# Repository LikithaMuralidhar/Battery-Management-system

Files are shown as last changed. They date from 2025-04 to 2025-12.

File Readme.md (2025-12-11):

# Battery Management System for 48V Lithium-Ion Battery Pack

**A comprehensive BMS solution for 48V Li-Ion battery packs with real-time monitoring and protection**

</div>

---

## Table of Contents

- [Overview](#-overview)
- [Features](#-features)
- [Specifications](#-specifications)
- [Hardware Components](#-hardware-components)
- [PCB Design](#-pcb-design)
- [Software Interface](#-software-interface)
- [Installation](#-installation)
- [Usage](#-usage)
- [Results](#-results)
- [Safety](#-safety)
- [Contributing](#-contributing)
- [Acknowledgments](#-acknowledgments)

---

## Overview

This project presents a complete Battery Management System (BMS) designed for 48V Lithium-Ion battery packs. The system provides comprehensive monitoring, protection, and balancing capabilities for applications such as electric vehicles, e-bikes, and energy storage systems.

### Key Highlights

-  13S10P Configuration (130 cells total)
-  Real-time monitoring via JBD Tools software
- Active cell balancing
- Multiple protection mechanisms
- Open-source PCB design using KiCad
- Tested with 1.2kW BLDC Hub Motor

---

## Features

### Protection Systems

| Feature | Description |
|---|---|
| **Overvoltage Protection** | Individual cell and pack monitoring |
| **Undervoltage Protection** | Prevents deep discharge damage |
| **Overcurrent Protection** | Charging (6.5A) and discharging limits |
| **Temperature Monitoring** | Real-time thermal tracking |
| **Cell Balancing** | Automatic balancing (±40mV threshold) |
| **Short Circuit Protection** | Immediate fault detection |
| **MOSFET Control** | Separate charge/discharge management |

### Monitoring Capabilities

- Real-time voltage for all 13 series cells
- Pack voltage measurement
- Bidirectional current sensing
- Temperature monitoring
- State of Charge (SoC) estimation
- Cycle count tracking
- Comprehensive alert system

---

## Specifications

### Battery Pack

```yaml
Voltage: 48V (46.8V nominal)
Configuration: 13S10P (13 series, 10 parallel)
Total Cells: 130 cells
Cell Type: 18650 Lithium-Ion
Cell Voltage: 3.6V nominal
Cell Capacity: 2900mAh (2.9Ah)
Pack Capacity: 29Ah
Total Energy: ~1.4kWh
```

### Load System

```yaml
Motor Type: BLDC Hub Motor
Motor Rating: 48V, 530 RPM, 1.2kW
Charger: 54.2V, 6A
Max Charging Current: 6.35A
Operating Temperature: -20°C to 60°C
```

### Protection Thresholds

| Parameter | Min | Max | Unit |
|---|-----|-----|---|
| Cell Voltage | 2.5 | 4.2 | V |
| Pack Voltage | 32.5 | 54.6 | V |
| Charge Current | - | 6.5 | A |
| Discharge Current | - | 30 | A |
| Temperature | -10 | 60 | °C |

---

## Hardware Components

### Main Components

```
├── BMS Protection Board
│   ├── Microcontroller (STM32/ATmega)
│   ├── Voltage Sensing ICs
│   ├── Current Sensors
│   └── UART Communication
│
├── Power Stage
│   ├── Charge MOSFET
│   ├── Discharge MOSFET
│   └── Gate Drivers
│
├── Sensors
│   ├── NTC Thermistors
│   ├── Current Shunt Resistors
│   └── Voltage Divider Networks
│
└── Load System
    ├── BLDC Hub Motor
    ├── Motor Controller
    └── Throttle Interface
```

### Bill of Materials (BOM)

| Component | Quantity | Description |
|---|---|---|
| 18650 Li-Ion Cells | 130 | 2900mAh, 3.6V nominal |
| BMS IC | 1 | 13S protection board |
| N-Channel MOSFETs | 2 | Charge/Discharge control |
| Current Sensor | 1 | Hall effect or shunt-based |
| NTC Thermistor | 2-3 | Temperature monitoring |
| Nickel Strips | As needed | For spot welding |
| PCB | 1 | Custom designed |
| Connectors | Various | XT60, JST, etc. |

---

## PCB Design

### Design Tools

**Software:** [KiCad](https://www.kicad.org/) (Open-source EDA)

### Features
- Schematic capture with hierarchical design
- Multi-layer PCB layout
- DRC (Design Rule Check) compliant
- Gerber file generation
- 3D visualization
- SPICE simulation support

### Design Process

```mermaid
graph LR
    A[Schematic Design] --> B[Footprint Assignment]
    B --> C[PCB Layout]
    C --> D[Component Routing]
    D --> E[DRC Check]
    E --> F[Gerber Generation]
    F --> G[Manufacturing]
```

### PCB Specifications

- **Layers:** 2-4 layers
- **Dimensions:** Optimized for battery pack integration
- **Copper Weight:** 2oz for power traces
- **Finish:** HASL or ENIG
- **Files Included:**
  - Gerber files
  - Drill files
  - Pick and place files
  - BOM (Bill of Materials)

---

## Software Interface

### JBD Tools Software

#### Key Features

- **UART Communication** - Standard serial interface
- **Parameter Configuration** - Adjust protection thresholds
- **Real-time Monitoring** - Live data visualization
- **Alert System** - Protection status notifications
- **Data Logging** - Track battery performance

#### Monitored Parameters

```yaml
Cell Voltages: V1-V13 (individual)
Pack Voltage: Total voltage
Current: Charge/Discharge (A)
Temperature: Real-time (°C)
SoC: State of Charge (%)
Capacity: Remaining/Full (mAh)
Cycles: Total charge cycles
Balance Status: ON/OFF per cell
FET Status: Charge/Discharge MOSFET
Alerts: All protection triggers
```

---

## Installation

### Hardware Setup

#### 1. Battery Pack Assembly

```bash
# Materials Required
- 130x 18650 cells (matched capacity)
- Spot welding machine (5kVA recommended)
- Nickel strips (0.15mm thickness)
- Insulation sheets
- Heat shrink wrap
- BMS board
```

**Assembly Steps:**

1. **Cell Testing & Sorting**
   - Test all cells for capacity matching
   - Sort into groups with <50mAh difference
   - Charge all cells to 3.7V

2. **Spot Welding**
   - Create 10P groups using nickel strips
   - Connect 13 groups in series
   - Use proper welding current (50-80A, 0.1-0.2s)

3. **BMS Integration**
   - Connect balance wires (13 connections)
   - Connect main power terminals
   - Install temperature sensors
   - Mount BMS securely on pack

4. **Insulation & Packaging**
   - Apply insulation sheets
   - Wrap with heat shrink
   - Add terminal connectors

#### 2. Software Setup

```bash
# Download JBD Tools
# Available for Windows PC

1. Install JBD Tools software
2. Connect BMS via USB-UART adapter
3. Configure COM port settings
   - Baud rate: 9600
   - Data bits: 8
   - Stop bits: 1
   - Parity: None
```

### Configuration

```python
# Example protection parameters

Cell_OVP = 4.2V      # Overvoltage protection
Cell_UVP = 2.5V      # Undervoltage protection
Pack_OVP = 54.6V     # Pack overvoltage
Pack_UVP = 32.5V     # Pack undervoltage
Charge_OCP = 6.5A    # Charge overcurrent
Discharge_OCP = 30A  # Discharge overcurrent
Balance_Voltage = 40mV  # Balance threshold
Temp_High = 60°C     # High temperature limit
Temp_Low = -10°C     # Low temperature limit
```

---

## 📖 Usage

### Basic Operation

#### Charging

```bash
1. Connect approved charger (54.2V, 6A max)
2. Monitor charging via JBD Tools
3. Charging stops automatically when:
   - Pack voltage reaches 54.6V
   - Any cell reaches 4.2V
   - Current exceeds 6.5A
   - Temperature exceeds limits
```

#### Discharging

```bash
1. Connect load (e.g., BLDC motor)
2. Monitor discharge parameters
3. BMS will disconnect if:
   - Pack voltage < 32.5V
   - Any cell < 2.5V
   - Current exceeds limits
   - Temperature out of range
```

#### Cell Balancing

```bash
# Automatic process
- Activates when cell voltage difference > 40mV
- Balancing current: 50-100mA typical
- Status shown in JBD Tools as "ON"
- Typically occurs near full charge
```

### JBD Tools Interface

#### Main Display

```
┌─────────────────────────────────────────┐
│ Cell Voltages (V)  │  Balance │ Status  │
├─────────────────────────────────────────┤
│ Cell 1:  3.632     │          │  ✓      │
│ Cell 2:  3.631     │          │  ✓      │
│ ...                │          │         │
│ Cell 13: 3.637     │          │  ✓      │
├─────────────────────────────────────────┤
│ Pack Voltage:  47.39V                   │
│ Current:       0.00A                    │
│ Temperature:   24.3°C                   │
│ SoC:           45%                      │
│ Capacity:      12960/29000 mAh         │
│ Cycles:        22                       │
├─────────────────────────────────────────┤
│ Charge FET:    ON    Discharge FET: ON  │
└─────────────────────────────────────────┘
```

---

## 📊 Results

### Performance Validation

#### Test 1: Normal Operation
- **Pack Voltage:** 47.39V
- **Cell Voltage Range:** 3.632V - 3.667V (35mV spread)
- **Temperature:** 24°C
- **Status:** All protection systems operational 

#### Test 2: Charging Process
- **Charging Current:** 6.02A
- **Cell Voltage Range:** 3.693V - 3.737V
- **SoC:** 45% → Charging
- **Protection:** Overcurrent limit enforced at 6.5A 

#### Test 3: Cell Balancing
- **Balance Threshold:** 40mV
- **Active Balancing:** Cells 1, 5, 9 (marked "ON")
- **Pack Voltage:** 51.81V
- **SoC:** 74%
- **Result:** Successful voltage equalization 

#### Test 4: Discharging
- **Discharge Current:** -0.86A (motor at low speed)
- **Cell Voltage Range:** 3.617V - 3.658V
- **Pack Voltage:** 47.26V
- **SoC:** 45%
- **Motor Performance:** Stable operation 

### Key Achievements
 **Prototype Validation** - 4-cell design successfully scaled to 13S10P  
 **MATLAB Simulation** - Circuit analysis confirmed  
 **Protection Systems** - All safety mechanisms functional  
 **Temperature Monitoring** - Real-time tracking operational  
 **MOSFET Control** - Proper switching behavior verified  
 **Load Testing** - 1.2kW motor successfully powered  

---

## Safety

> Improper handling can result in fire, explosion, or injury.
> Always follow safety procedures.

### Safety Guidelines

#### DO:
- Use appropriate safety equipment (goggles, gloves)
- Work in well-ventilated areas
- Keep fire extinguisher nearby (Class D)
- Monitor temperature during operation
- Use manufacturer-approved chargers
- Inspect cells for damage before assembly
- Test BMS functionality before full assembly
- Store at 3.7-3.8V for long-term storage

#### DON'T:
- Exceed rated voltage or current limits
- Short circuit battery terminals
- Puncture or damage cells
- Expose to extreme temperatures
- Use damaged or swollen cells
- Charge unattended
- Bypass protection systems
- Mix cells of different capacities

### Emergency Procedures

```bash
# In case of thermal runaway:
1. Move to safe area away from flammable materials
2. Use Class D fire extinguisher
3. DO NOT use water
4. Evacuate area if fire spreads
5. Call emergency services
```

---

## Troubleshooting

### Common Issues

| Issue | Possible Cause | Solution |
|---|---|---|
| BMS not communicating | UART connection | Check COM port, baud rate |
| Cells not balancing | Voltage difference < 40mV | Normal, wait until higher SoC |
| Charge FET off | Overvoltage detected | Check cell voltages, reset BMS |
| Discharge FET off | Undervoltage detected | Charge battery pack |
| High temperature | Excessive current | Reduce load, improve cooling |
| SoC inaccurate | Calibration needed | Full charge/discharge cycle |

---

## Contributing

Contributions are welcome! Please follow these guidelines:

### How to Contribute

1. **Fork the repository**
2. **Create a feature branch** (`git checkout -b feature/AmazingFeature`)
3. **Commit changes** (`git commit -m 'Add AmazingFeature'`)
4. **Push to branch** (`git push origin feature/AmazingFeature`)
5. **Open a Pull Request**

### Development Setup

```bash
# Clone repository
git clone https://github.com/yourusername/48v-bms.git

# Navigate to project
cd 48v-bms

# Open KiCad project
kicad bms-48v.kicad_pro
```

### Code of Conduct

- Be respectful and inclusive
- Provide constructive feedback
- Focus on improving the project
- Follow coding standards

---

## 📁 Project Structure

```
48v-bms/
├── hardware/
│   ├── kicad/
│   │   ├── bms-schematic.kicad_sch
│   │   ├── bms-pcb.kicad_pcb
│   │   └── libraries/
│   ├── gerber/
│   │   └── manufacturing_files/
│   └── bom/
│       └── bill_of_materials.csv
│
├── software/
│   ├── jbd-tools/
│   │   └── configuration_files/
│   ├── matlab/
│   │   └── simulation_files/
│   └── firmware/
│       └── (firmware)
│
├── README.md
```

---

## 🎓 Acknowledgments

### Institution
**Department of Electrical and Electronics Engineering**  
**BNM Institute of Technology (BNMIT)**  
Academic Year: 2021-2022

### Special Thanks
- Faculty advisors for guidance and support
- Lab technicians for equipment access
- Fellow students for collaboration
- Open-source community (KiCad, GitHub)

### References
- Battery Management System Design Standards
- IEEE Standards for Battery Testing
- Lithium-Ion Battery Safety Guidelines
- KiCad PCB Design Best Practices

---

## Contact

### Project Maintainers

- **Email:** likithm18ee022@bnmit.edu.in
- **Institution:** BNMIT, Department of EEE

<div align="center">

**Made by BNMIT EEE Department**

[⬆ Back to Top](#-battery-management-system-for-48v-lithium-ion-battery-pack)

</div>

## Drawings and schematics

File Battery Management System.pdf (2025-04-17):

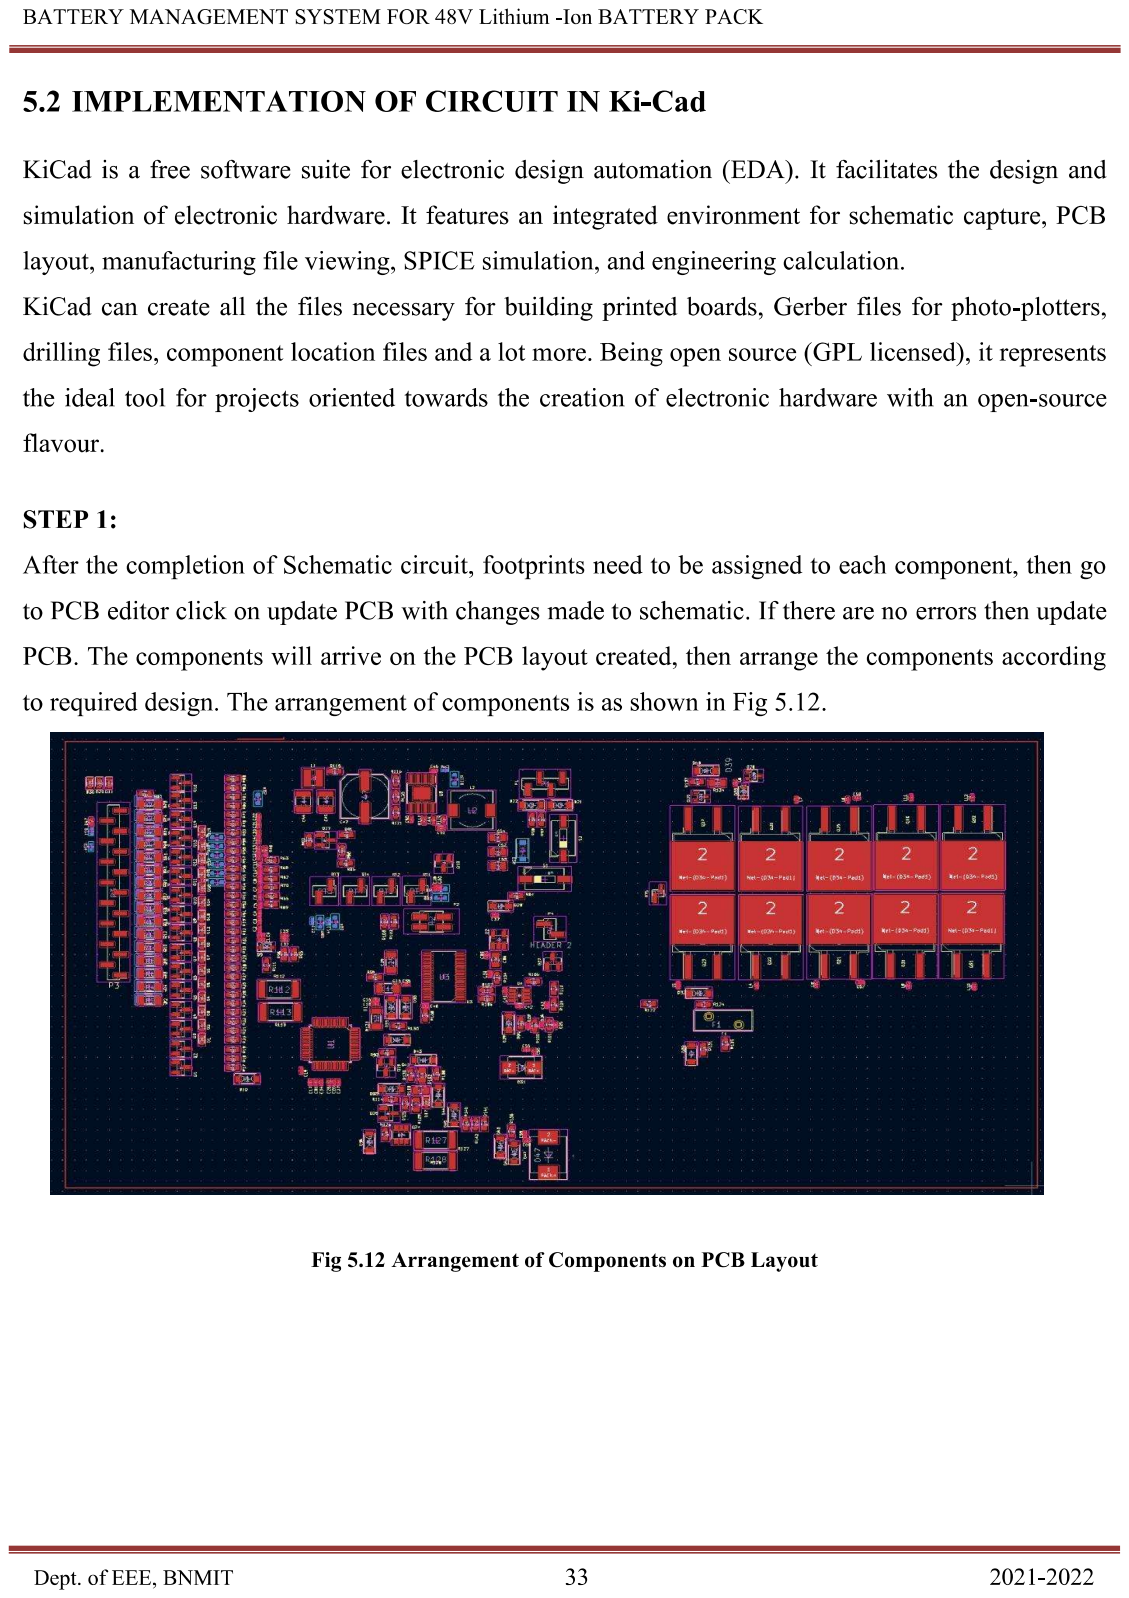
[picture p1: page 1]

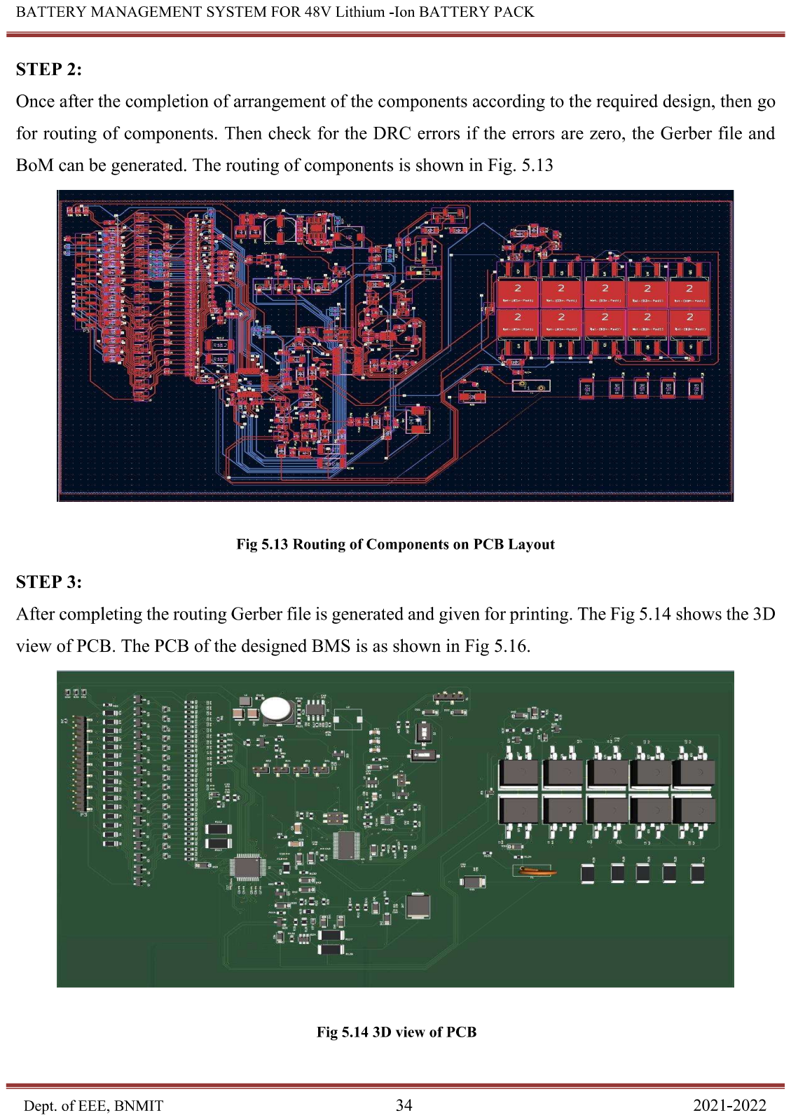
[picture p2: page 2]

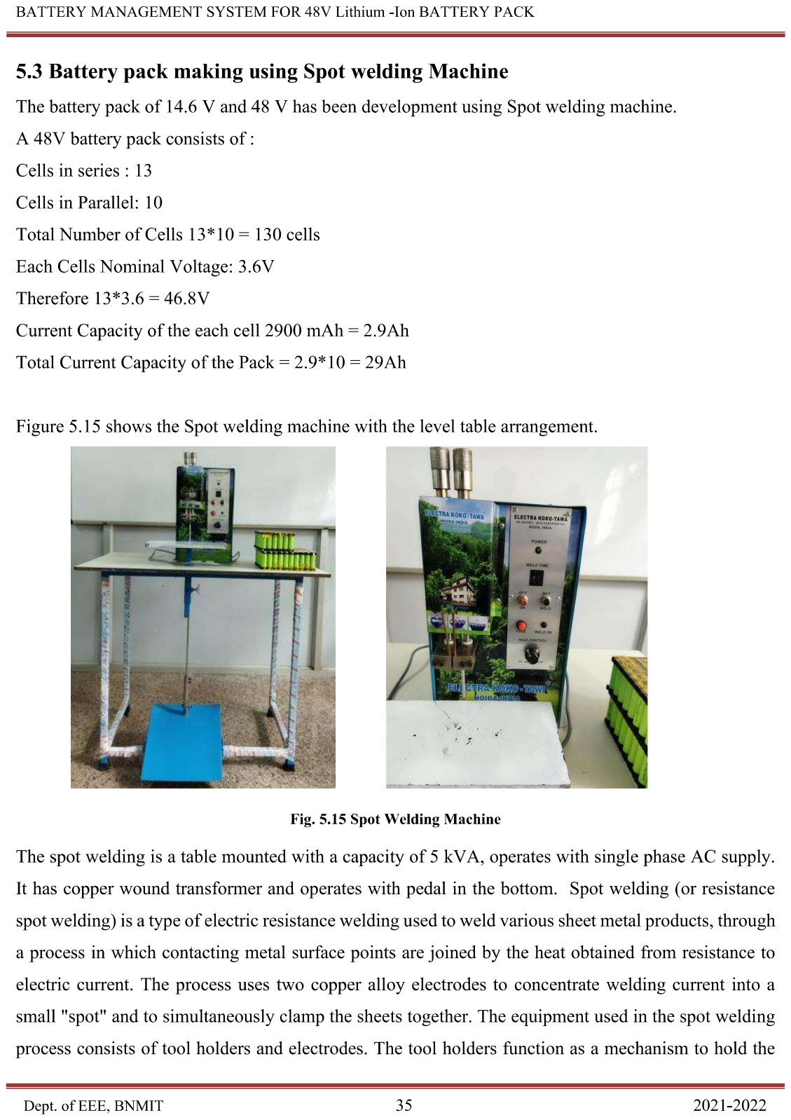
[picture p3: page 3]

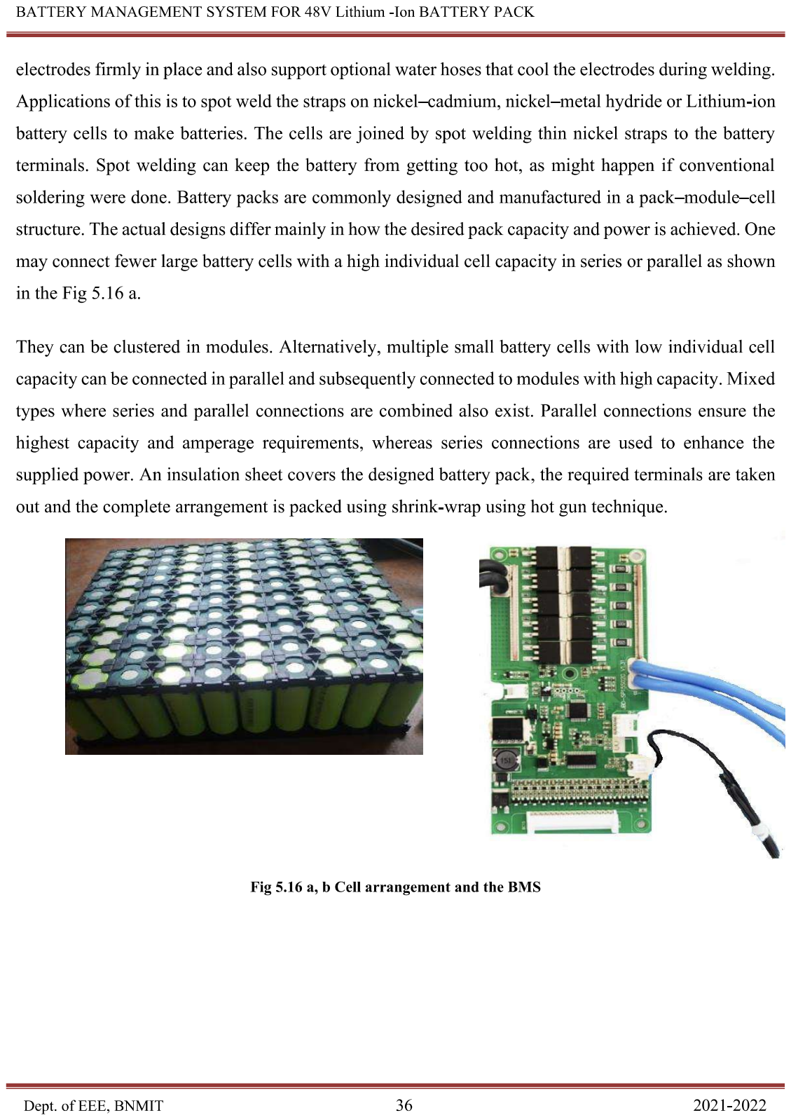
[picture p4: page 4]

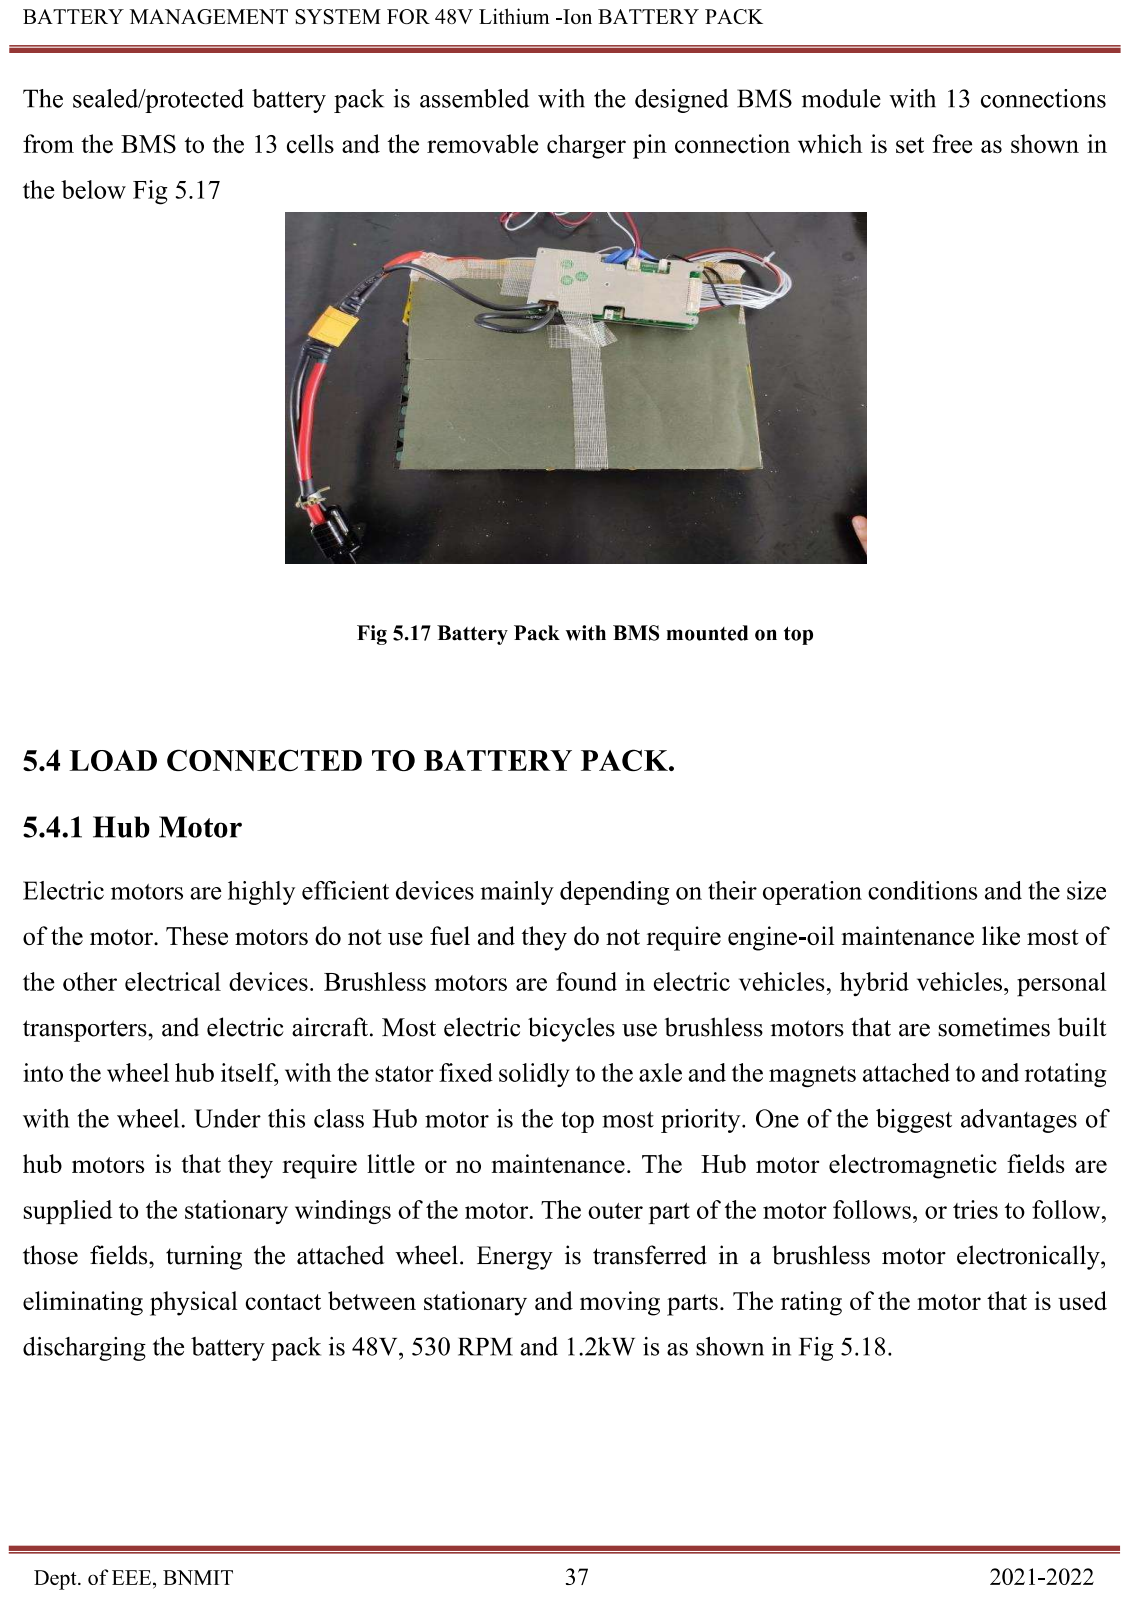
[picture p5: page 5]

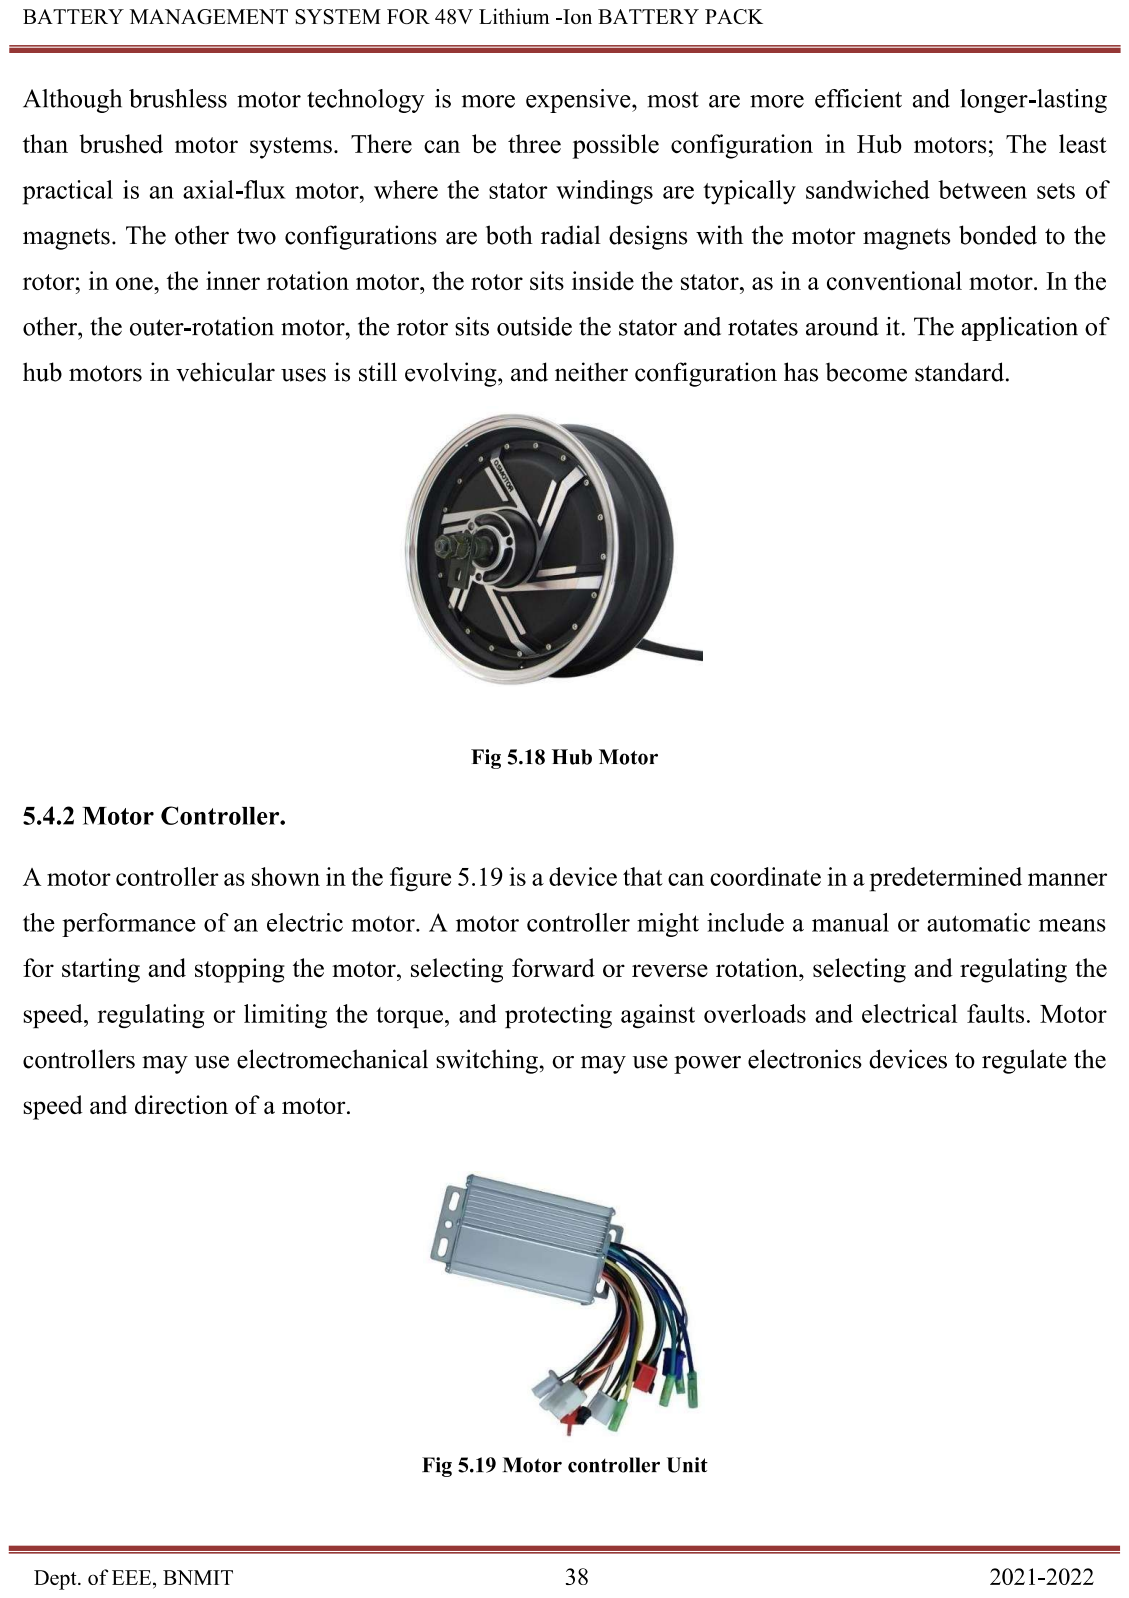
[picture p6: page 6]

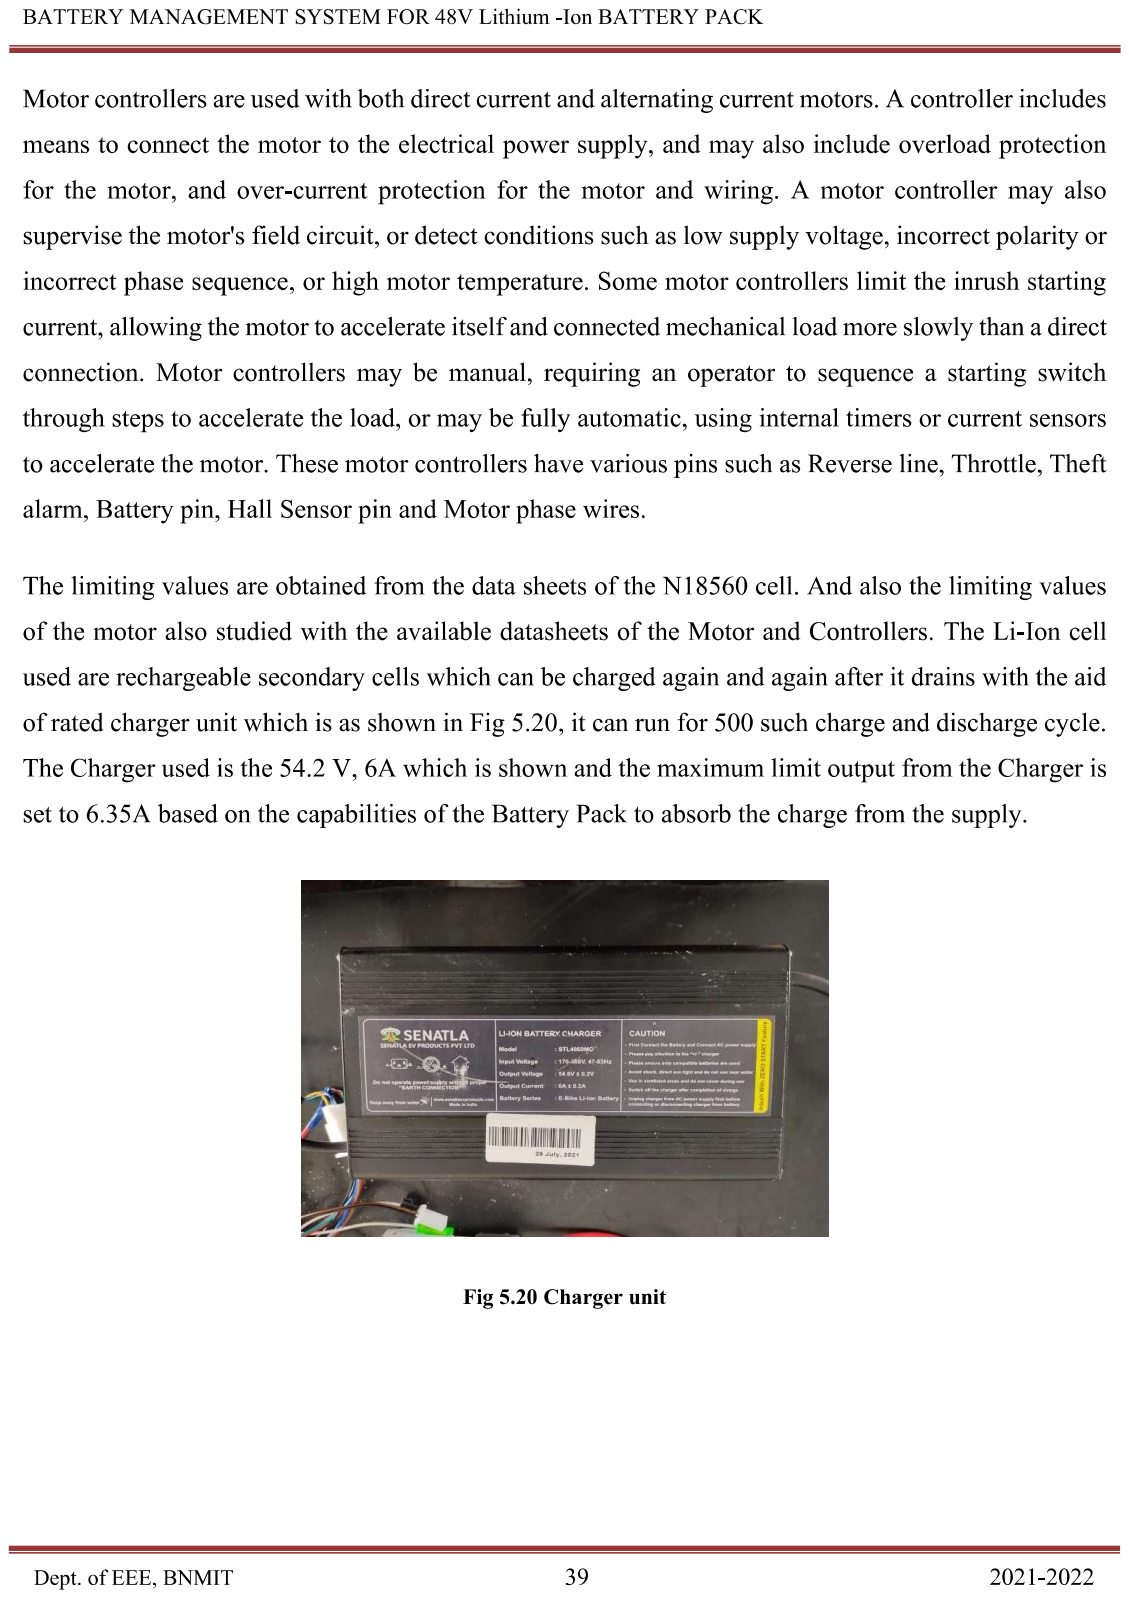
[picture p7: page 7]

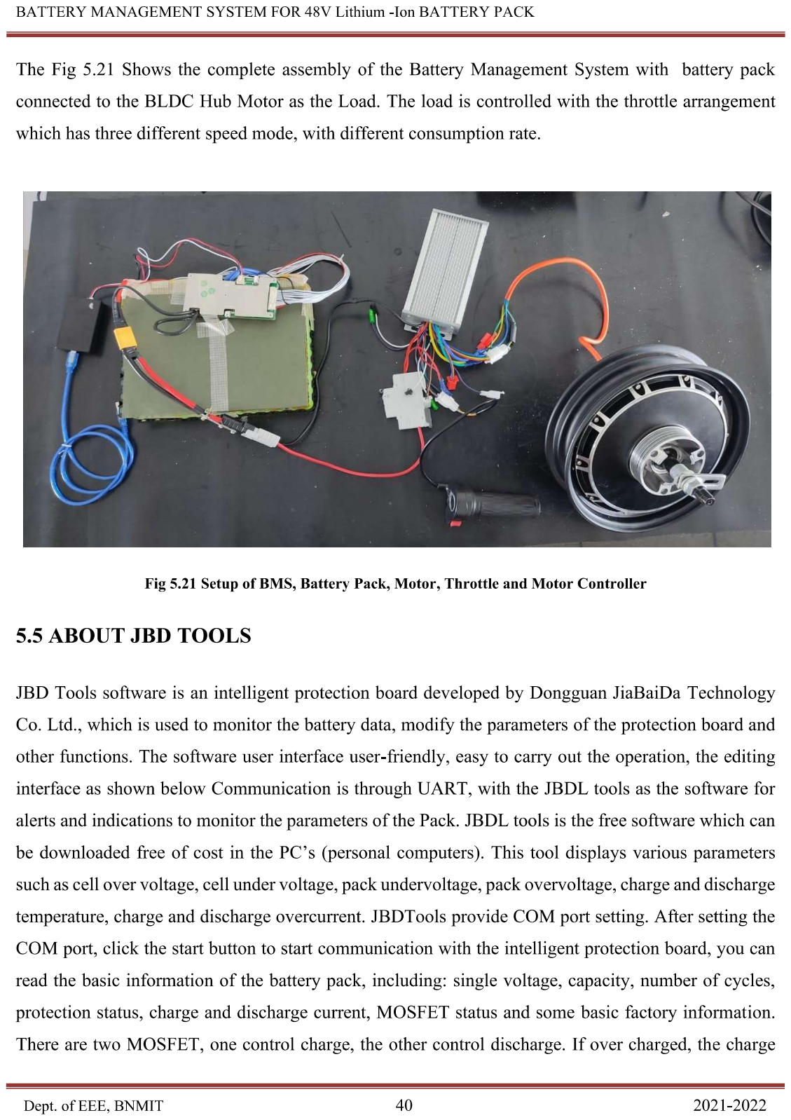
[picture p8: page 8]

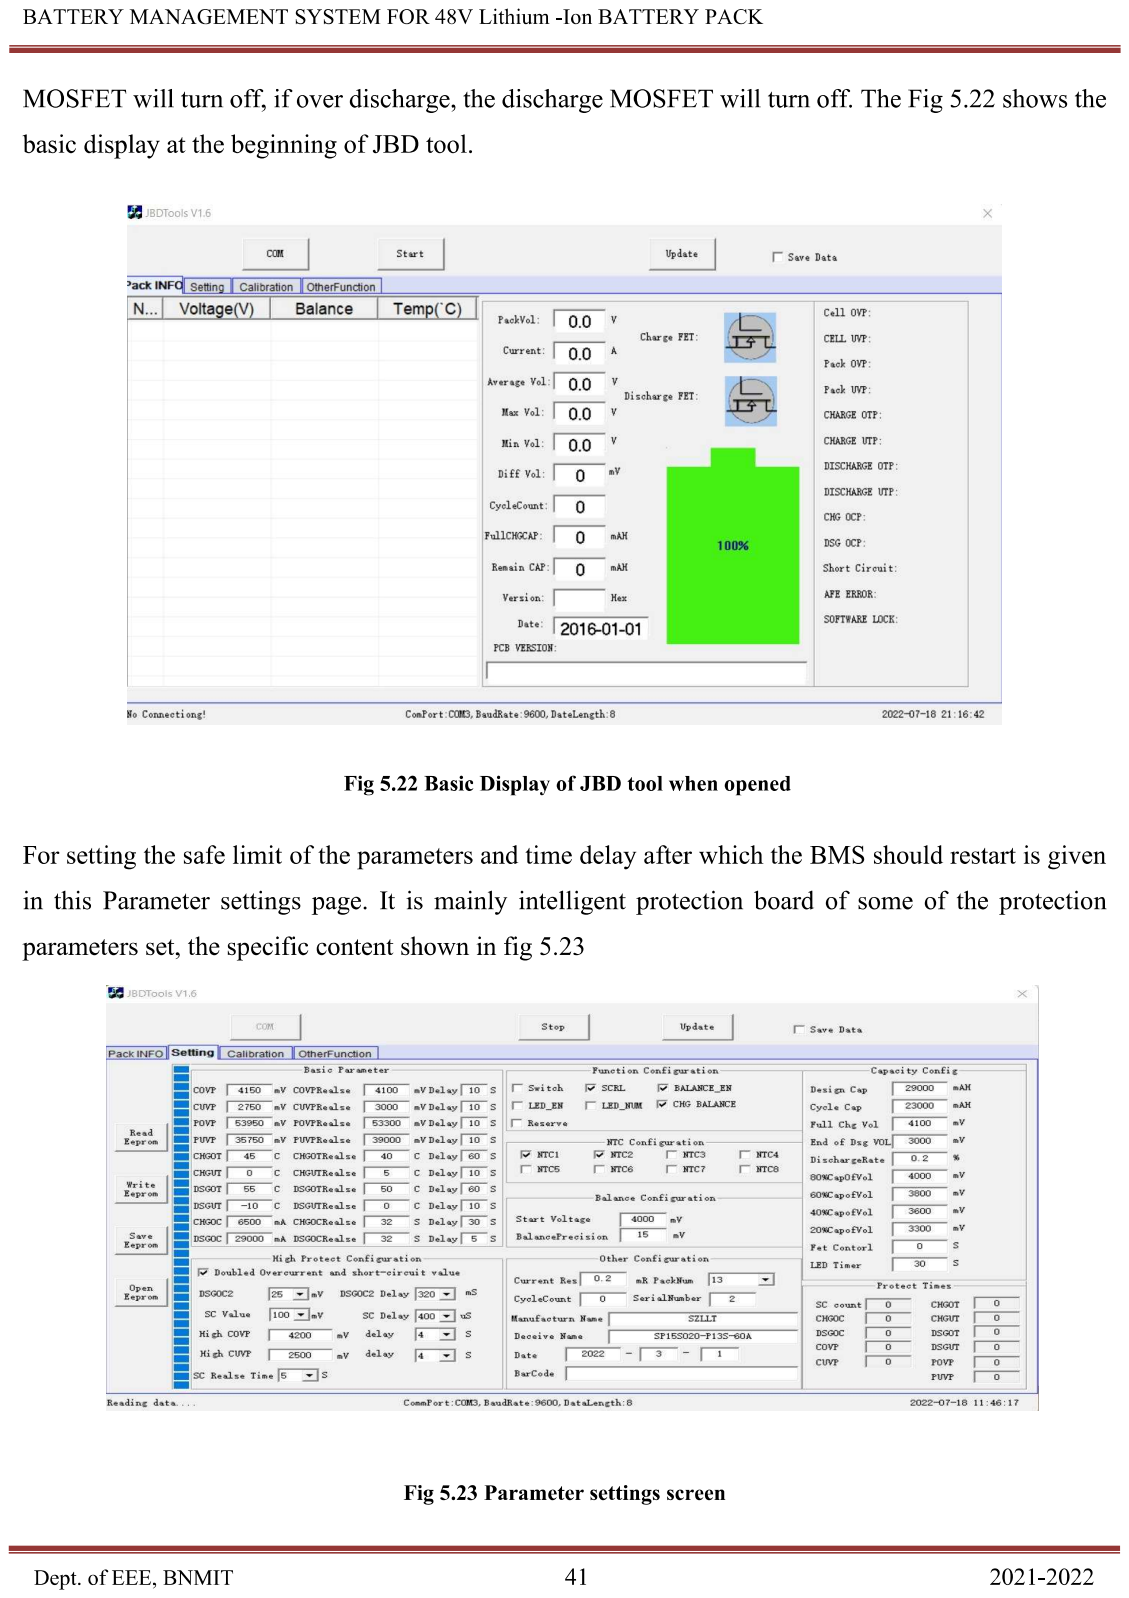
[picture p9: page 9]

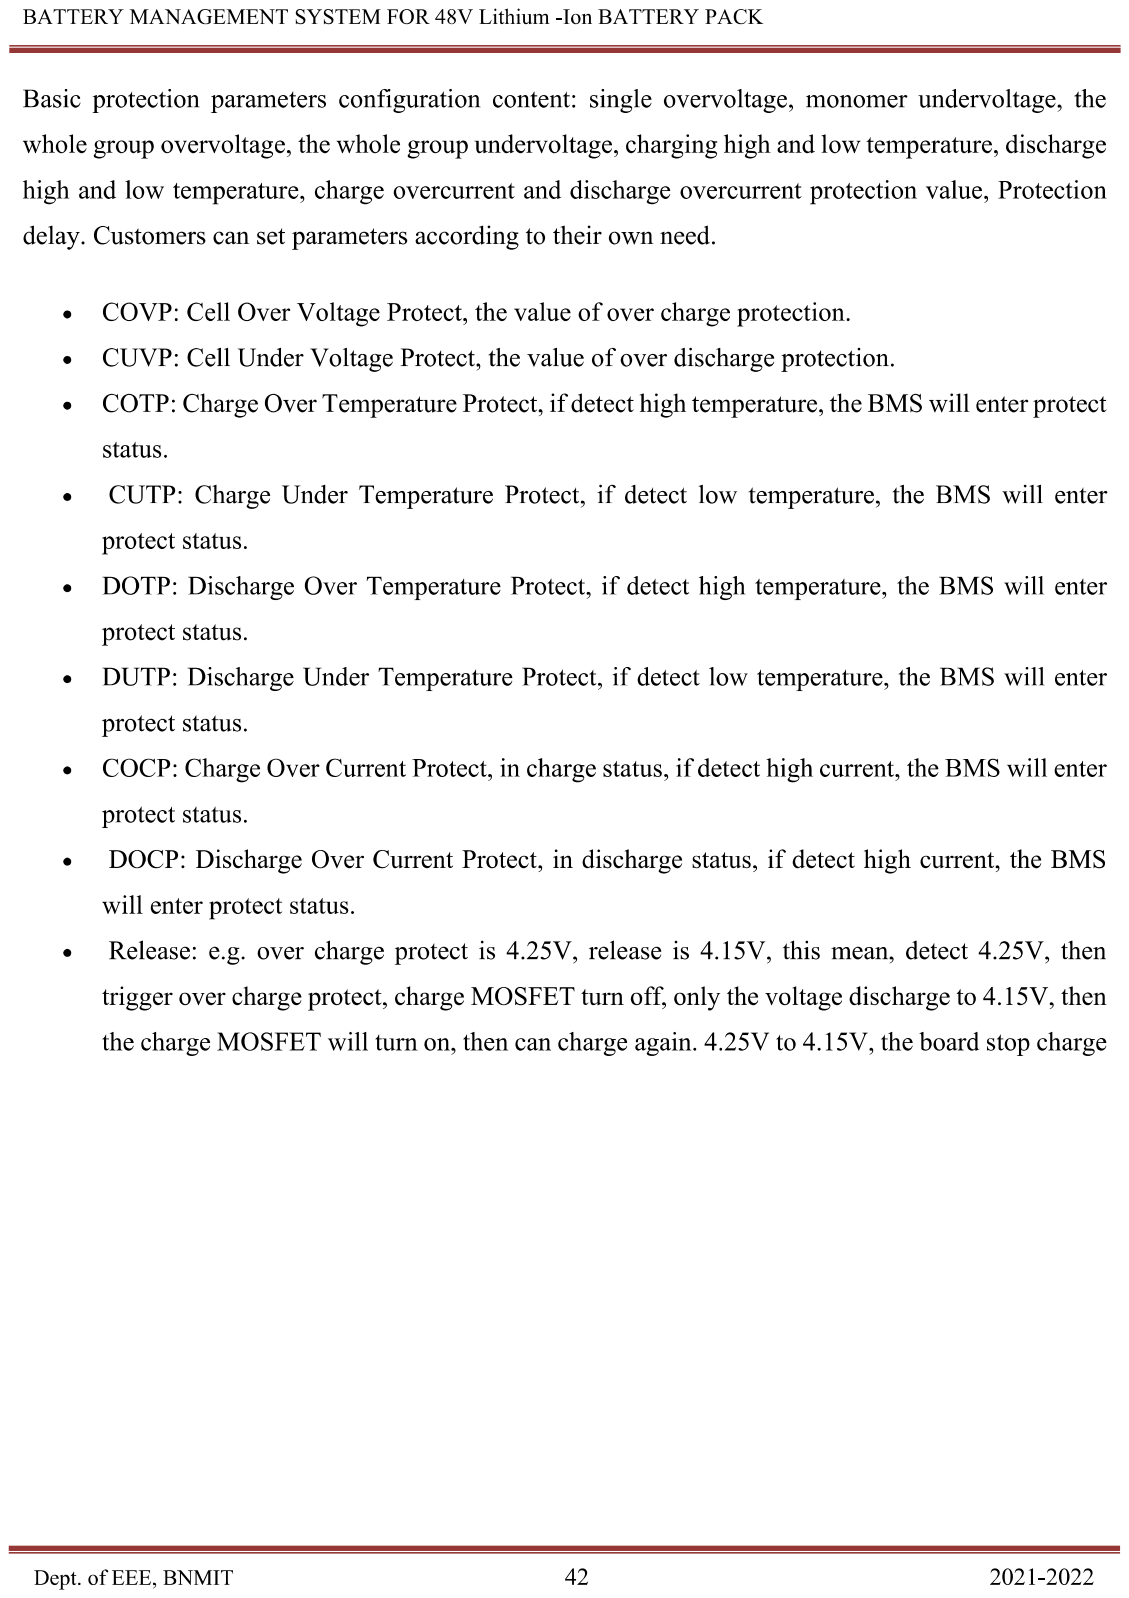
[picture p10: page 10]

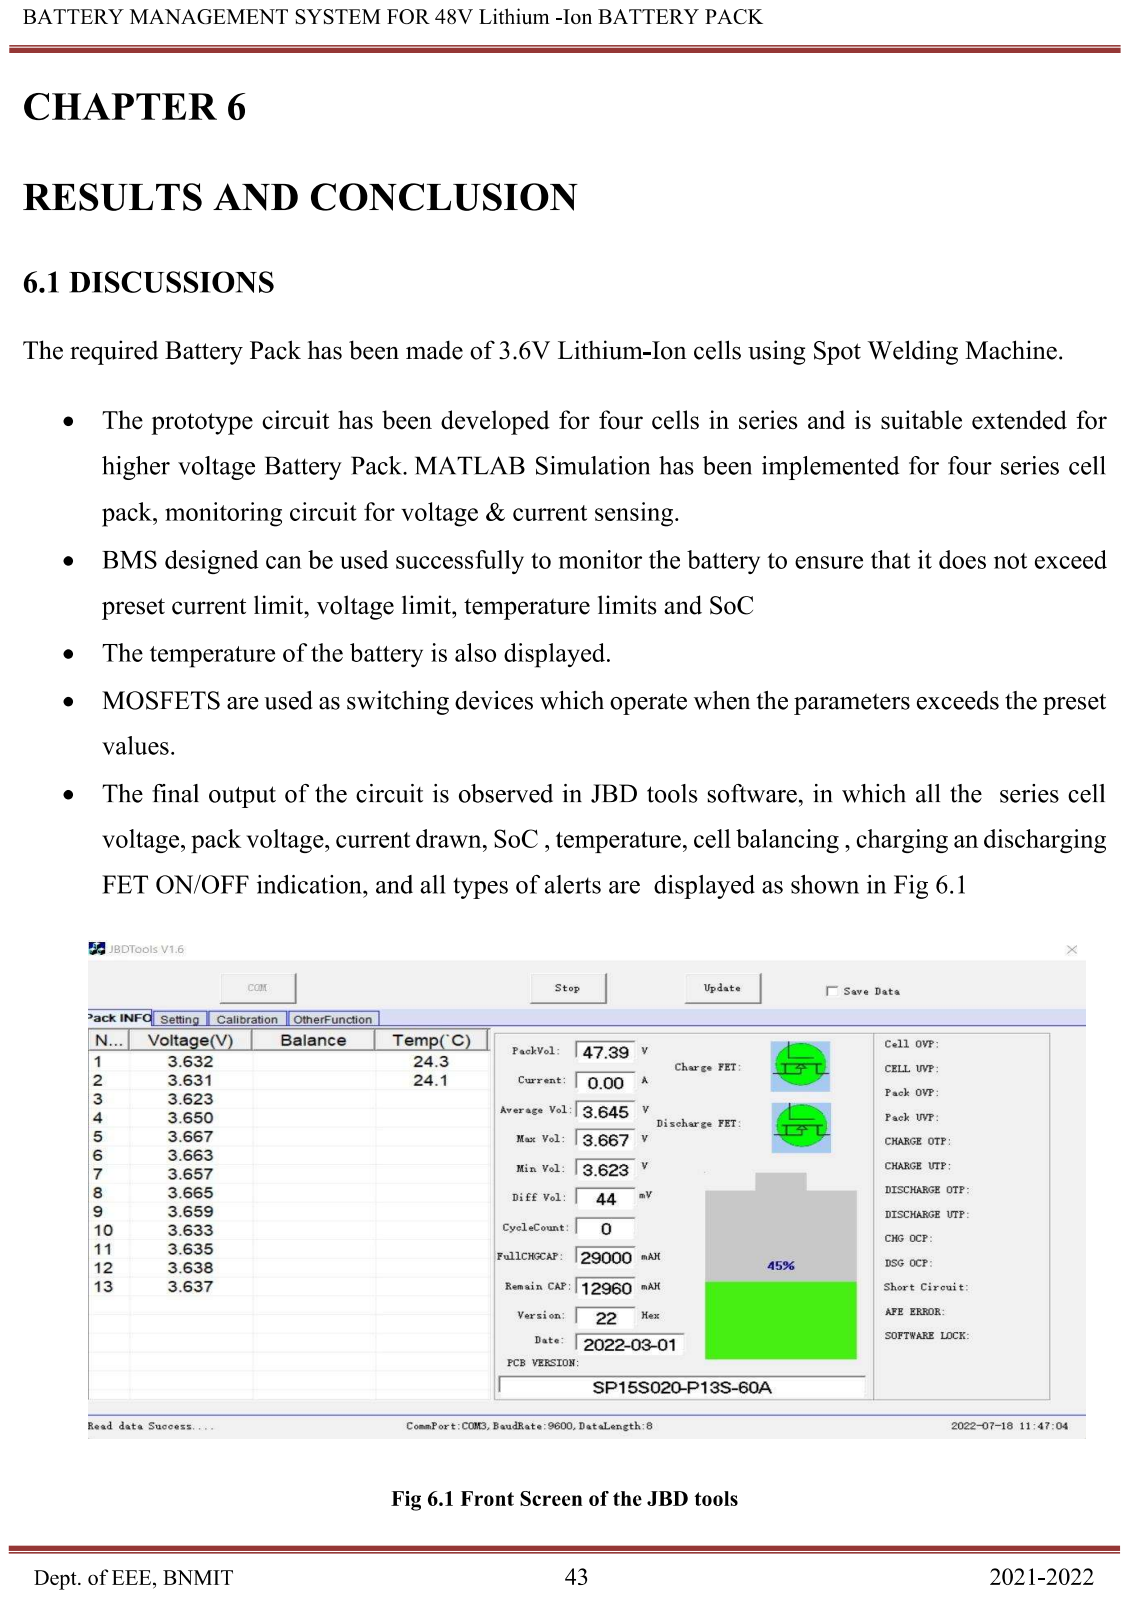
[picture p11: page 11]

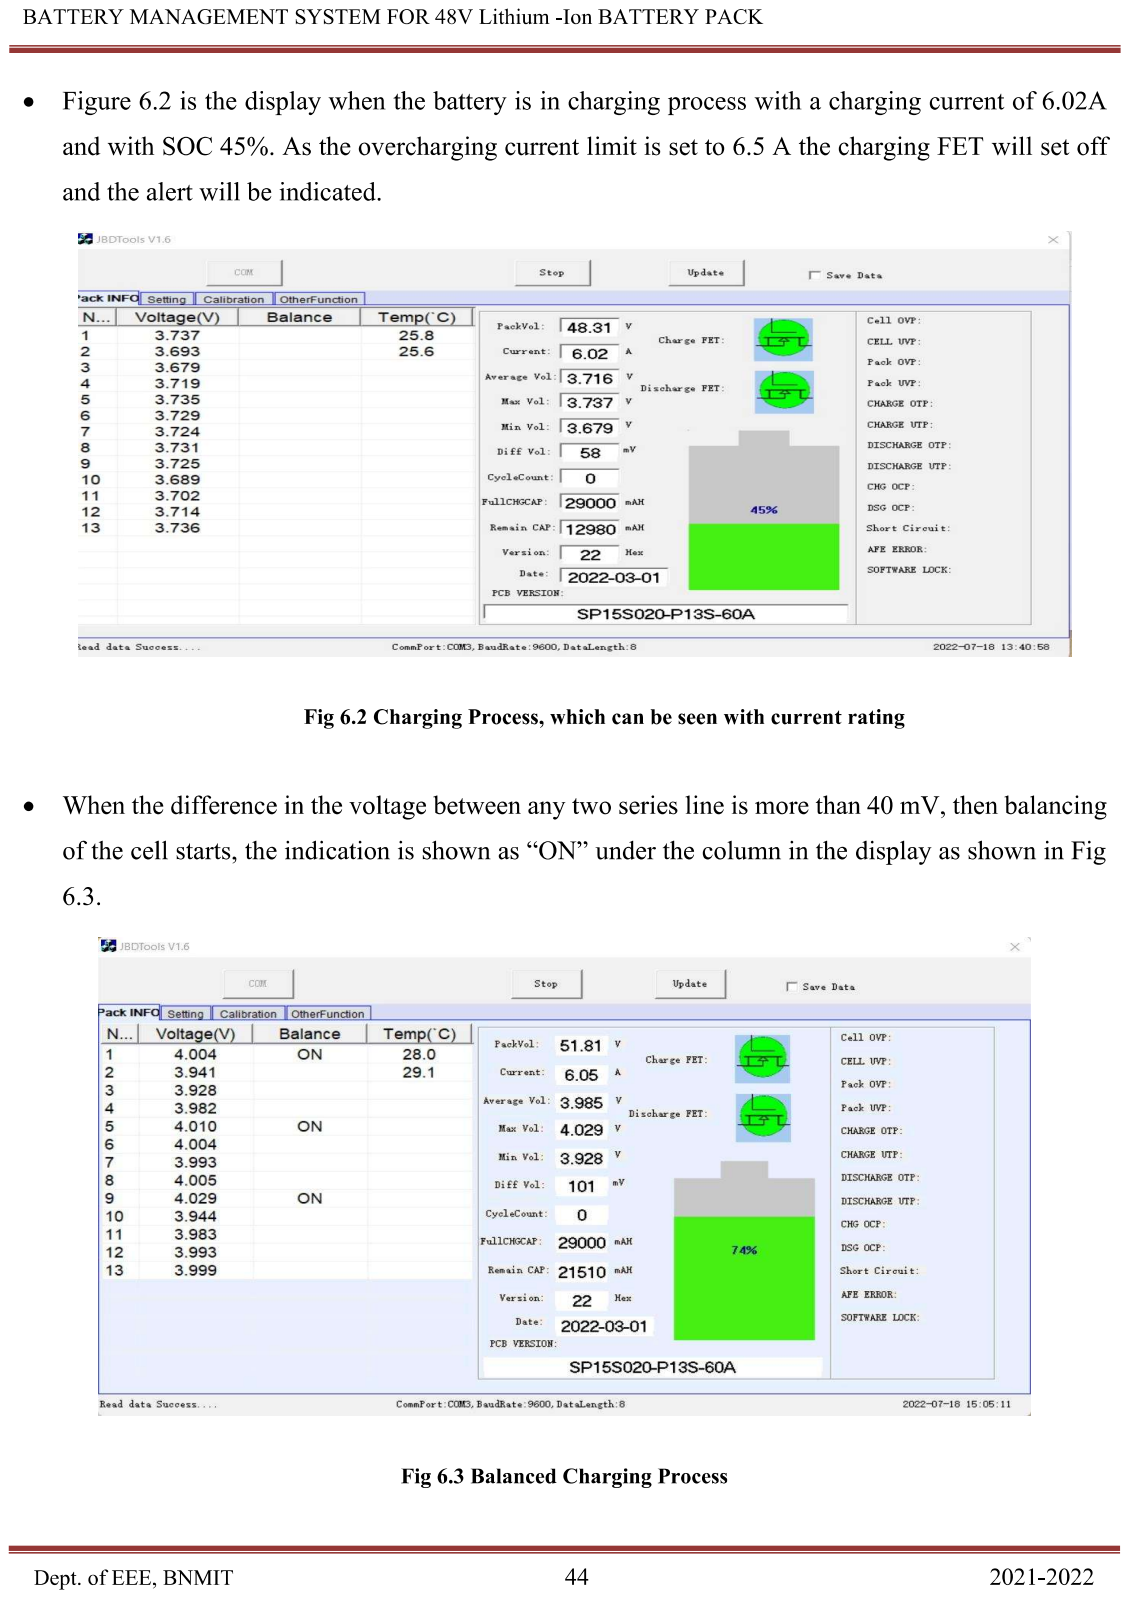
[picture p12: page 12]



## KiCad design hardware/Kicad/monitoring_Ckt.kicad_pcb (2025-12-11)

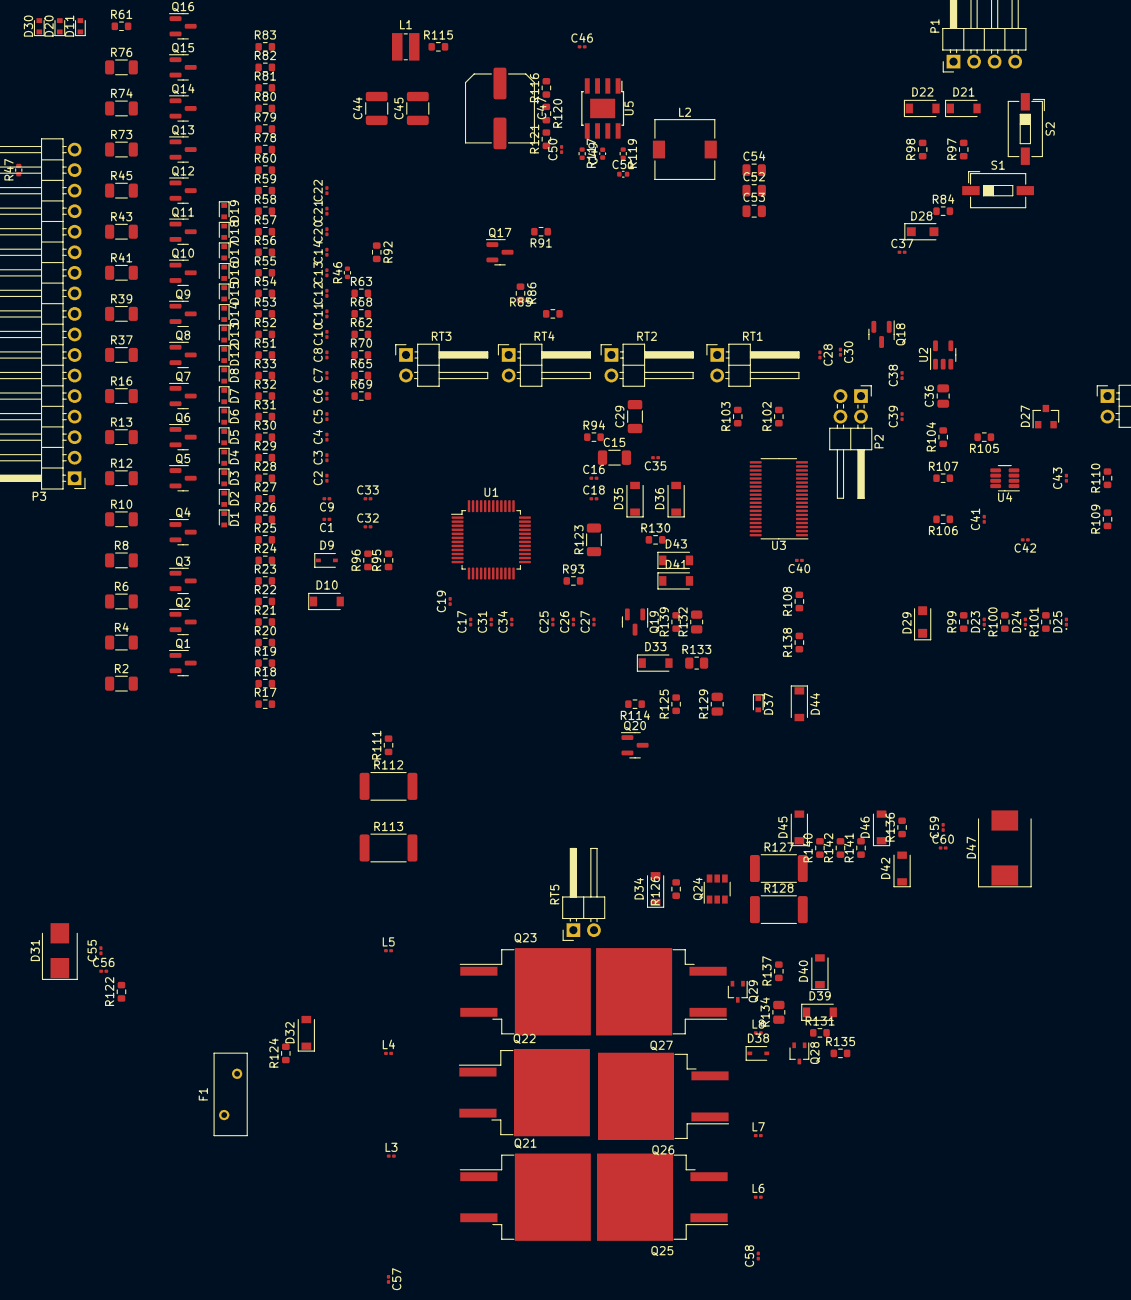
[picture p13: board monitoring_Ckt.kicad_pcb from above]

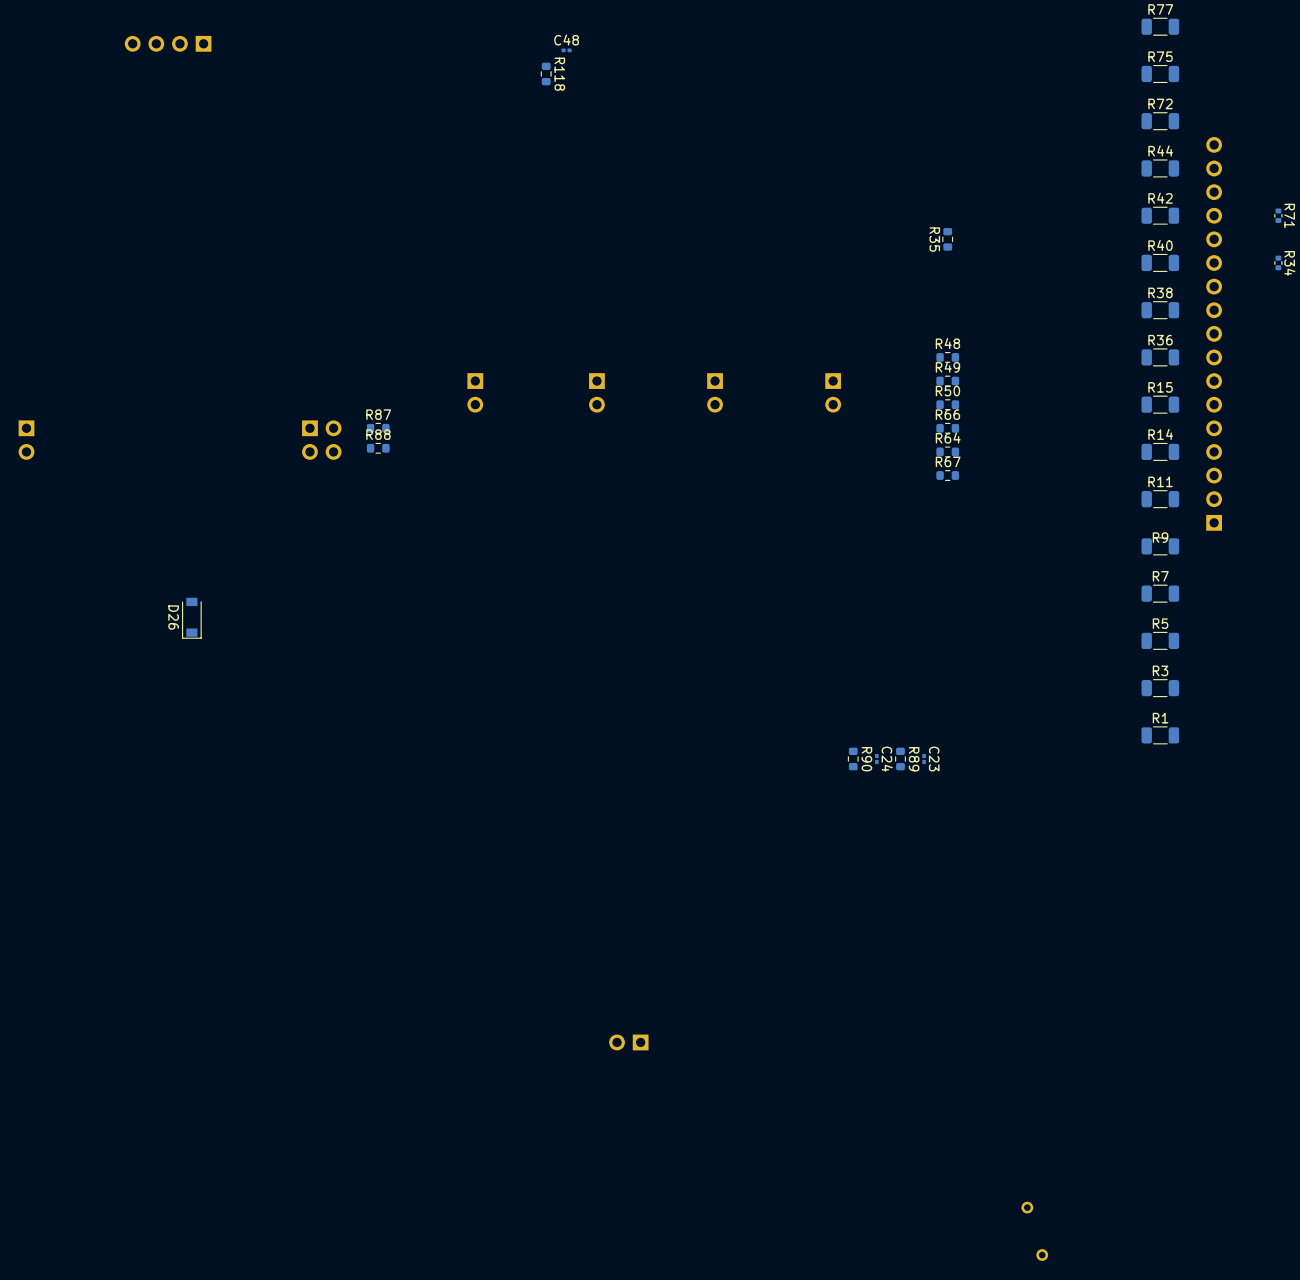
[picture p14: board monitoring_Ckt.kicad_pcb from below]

Board: 2 copper layers, 303 parts (34 on the bottom side), 181 nets, no tracks yet.

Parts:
C1, C2, C3, C4, C5, C6, C7, C8, C9, C10, C11, C12, C13, C14, C20, C21, C22: 0.22uf; C_0201_0603Metric
C15: 2.2uF; C_1206_3216Metric
C16, C17, C23, C24, C50: 100pF; C_0201_0603Metric
C18, C25, C26: 1uF; C_0201_0603Metric
C19, C37: 2.2uF; C_0201_0603Metric
C27: 0.022uF; C_0201_0603Metric
C28, C30, C31, C34: 470uF; C_0201_0603Metric
C29: 1uF; C_1206_3216Metric
C32, C38, C41, C42, C43, C46, C55, C56, C57, C58, C59, C60: 0.1uF; C_0201_0603Metric
C33: 100pFD; C_0201_0603Metric
C35: 440pF; C_0201_0603Metric
C36: 10uF; C_0805_2012Metric
C39: 1000pF; C_0201_0603Metric
C40: 470pF; C_0201_0603Metric
C44, C45: 4.7uF; C_1210_3225Metric
C47: 10uF; C_Elec_8x6.2
C48: NC; C_0201_0603Metric
C49: 2200pF; C_0402_1005Metric
C51: 1500pF; C_0402_1005Metric
C52, C53, C54: 4.7uF; C_0805_2012Metric
D1, D2, D3, D4, D5, D6, D7, D8, D12, D13, D14, D15, D16, D17, D18, D19: 5.6V; D_SOD-523
D9: BAT42WS-7-F; D_SOD-323
D10, D21, D22: MMSZ4685T1G 3.6V; D_SOD-123
D11, D20, D30, D37: BAS516,115; D_SOD-523
D23, D24, D25: 150060RS75000; LED_0201_0603Metric
D26: MMSZ4690T1G 5.6V; D_SOD-123
D27: NUP3105LT1G; D_SOT-23_ANK
D28, D29: PMEG2010AEH,115; D_SOD-123F
D31: SMBJ60A-13-F 60V; D_SMB
D32, D34, D39: 16V; D_SOD-123
D33, D41, D43: 75V; D_SOD-123
D35: NC; D_SOD-123
D36, D42, D44, D45, D46: BAT46W-7-F; D_SOD-123
D38: BZT52C5V1S-7-F 5.1V; D_SOD-323
D40: MMSZ5246B-7-F; D_SOD-123
D47: D_SMC
F1: 0678L9300-02; Fuse_BelFuse_0ZRE0016FF_L9.9mm_W3.8mm
L1: 10uH; L_Wuerth_MAPI-3015
L2: 68uH; L_7.3x7.3_H3.5
L3, L4, L5, L8: 600 ohm; L_0201_0603Metric
L6, L7: 600ohm; L_0201_0603Metric
P1: HEADER 4; PinHeader_1x04_P2.54mm_Horizontal
P2: HEADER 2X2; PinHeader_2x02_P2.54mm_Horizontal
P3: HEADER 17; PinHeader_1x17_P2.54mm_Horizontal
P4: HEADER 2; PinHeader_1x02_P2.54mm_Horizontal
Q1, Q2, Q3, Q4, Q5, Q6, Q7, Q8, Q9, Q10, Q11, Q12, Q13, Q14, Q15, Q16: DMG2302UK-7; SOT-23
Q17: ZXMP10A13FTA; SOT-23
Q18: BSS123; SOT-23
Q19: ZXTN25100BFHTA; SOT-23
Q20: DMN10H220L-7; SOT-23
Q21, Q22, Q23, Q25, Q26, Q27: CSD19536KTT; TO-263-2
Q24: FDC3535; SuperSOT-6
Q28: DMG1013UW-7; SOT-323_SC-70
Q29: 2N7002W-7-F; SOT-323_SC-70
R1, R3, R5, R7, R10, R12, R14, R15, R36, R38, R40, R42, R45, R72, R75, R76: CRCW120680R6FKEA; R_1206_3216Metric
R2, R4, R6, R8, R9, R11, R13, R16, R37, R39, R41, R43, R44, R73, R74, R77: 80.6; R_1206_3216Metric
R17, R19, R21, R23, R25, R27, R29, R31, R33, R52, R54, R56, R58, R60, R61, R79, R81, R83, R87, R88, R93, R95, R96, R97, R98, R105, R106, R107, R115, R130: 100; R_0603_1608Metric
R18, R20, R22, R24, R26, R28, R30, R32, R51, R53, R55, R57, R59, R78, R80, R82, R89, R90, R102, R103, R108: 10K; R_0603_1608Metric
R34, R46, R47, R71, R117: 0; R_0402_1005Metric
R35, R48, R49, R50, R62, R63, R64, R65, R66, R67, R68, R69, R70, R111: 0; R_0603_1608Metric
R84, R136: 10k; R_0603_1608Metric
R85: 13.3k; R_0603_1608Metric
R86: 665k; R_0603_1608Metric
R91: 3.3M; R_0603_1608Metric
R92, R126: 1.0M; R_0603_1608Metric
R94: 249; R_0603_1608Metric
R99, R100, R101: 470; R_0603_1608Metric
R104: 47.0k; R_0603_1608Metric
R109, R110: 60.4; R_0603_1608Metric
R112, R113: 0.002; R_2512_6332Metric
R114, R139: 5.1k; R_0603_1608Metric
R116: 82.5k; R_0603_1608Metric
R118: NC; R_0603_1608Metric
R119: 52.3k; R_0402_1005Metric
R120: 63.4K; R_0603_1608Metric
R121: 200K; R_0603_1608Metric
R122: 200; R_0603_1608Metric
R123: 499; R_1206_3216Metric
R124, R131, R137: 10M; R_0603_1608Metric
R125, R138, R140: 49.9k; R_0603_1608Metric
R127, R128: 510; R_2512_6332Metric
R129: 56k; R_0805_2012Metric
R132, R133, R134: 511; R_0805_2012Metric
R135: 511; R_0603_1608Metric
R141, R142: 20k; R_0603_1608Metric
RT1, RT2, RT3: Thermistor_NTC; PinHeader_1x02_P2.54mm_Horizontal
RT4: RT4; PinHeader_1x02_P2.54mm_Horizontal
RT5: TMP6131DECR; PinHeader_1x02_P2.54mm_Horizontal
S1: RS-032G05A3-SM_RT; SW_DIP_SPSTx01_Slide_6.7x4.1mm_W6.73mm_P2.54mm_LowProfile_J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
S2: SW_SPST; SW_DIP_SPSTx01_Slide_6.7x4.1mm_W6.73mm_P2.54mm_LowProfile_J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
U1: BQ76952PFBR; TQFP-48_7x7mm_P0.5mm
U2: TLV70433DBVT; SOT-23-5
U3: MSP430FR2155TDBTR; TSSOP-38_4.4x9.7mm_P0.5mm
U4: TCAN1044VDDFR; SOT-23-8
U5: LM5163DDAR; TI_SO-PowerPAD-8

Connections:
/AUX POWER/POW_EN: U3.18 (P4.5/UCB1CLK), U5.3 (EN/UVLO)
/BAT+: C56.2, D31.1, F1.1
/BAT-: C55.1, D31.2, R96.1, R111.2, R112.1, R113.1
/HIGH SIDE MOSFETS AND DRIVERS/CHG: R123.1, U1.45 (CHG)
/HIGH SIDE MOSFETS AND DRIVERS/Fuse: D29.1, Q20.1, R114.2
/HIGH SIDE MOSFETS AND DRIVERS/PDSG: D33.1, R125.1, U1.39 (PDSG)
/MCU and Communication/3V3: C36.1, C38.1, C42.1, P1.4, R102.1, R103.1, R104.2, U2.3 (OUT), U3.10 (DVCC), U4.5 (VIO)
/MCU and Communication/5V: C37.2, C41.1, C51.2, C52.1, C53.1, C54.1, D26.1, D28.1, L2.2, R121.1, U2.2 (IN), U2.4 (NC_1), U4.3 (VCC)
/MCU and Communication/ALERT: U1.25 (ALERT), U3.20 (P4.3/UCA1TXD/UCA1SIMO/~UCA1TXD)
/MCU and Communication/BATS_EN: Q18.1, U3.19 (P4.4/UCB1STE)
/MCU and Communication/BAT_ADC: C35.1, R85.1, R86.1, U3.28 (P1.7/UCA0TXD/UCA0SIMO/TB0.2/TDO/A7/VREF+)
/MCU and Communication/CANH: D27.1 (K), P4.1, R110.2, U4.7 (CANH)
/MCU and Communication/CANL: D27.2 (K), P4.2, R109.1, U4.6 (CANL)
/MCU and Communication/DCSG: U1.31 (DCHG), U3.22 (P4.1/UCA1CLK)
/MCU and Communication/DDSG: U1.32 (DDSG), U3.23 (P4.0/UCA1STE/ISOTXD/ISORXD)
/MCU and Communication/FETOFF: C23.2, R89.2, U1.30 (DFETOFF), U3.21 (P4.2/UCA1RXD/UCA1SOMI/~UCA1RXD)
/MCU and Communication/FUSE_MCU: D29.2, U3.7 (P1.0/UCB0STE/SMCLK/COMP0.0/A0/VEREF+)
/MCU and Communication/LED1: D23.1, U3.6 (P1.1/UCB0CLK/ACLK/COMP0.1/A1)
/MCU and Communication/LED2: D24.1, U3.5 (P1.2/UCB0SIMO/UCB0SDA/TB0TRG/A2/VEREF-)
/MCU and Communication/LED3: D25.1, U3.4 (P1.3/UCB0SOMI/UCB0SCL/A3)
/MCU and Communication/PTC_PULL: R108.1, U3.38 (P3.3)
/MCU and Communication/RXD: R106.1, U3.1 (P3.2)
/MCU and Communication/SBCLK: R97.2, U3.8 (TEST/SBWTCK)
/MCU and Communication/SBIO: C39.2, R98.2, R104.1, S2.1 (A), U3.9 (RST/NMI/SBWTDIO)
/MCU and Communication/SCL: P2.1, R87.2, R103.2
/MCU and Communication/SCL_MCU: P2.2, U3.16 (P4.7/UCB1SOMI/UCB1SCL)
/MCU and Communication/SDA: P2.3, R88.2, R102.2
/MCU and Communication/SDA_MCU: P2.4, U3.17 (P4.6/UCB1SIMO/UCB1SDA)
/MCU and Communication/SHUT: C24.2, R90.2, U1.33 (RST_SHUT), U3.24 (P2.3/TB1TRG)
/MCU and Communication/STB: R105.2, U3.3 (P3.0/MCLK)
/MCU and Communication/TXD: R107.1, U3.2 (P3.1)
/Monitor and Cell Balancing/5V_AFE: C25.1, D28.2, U1.34 (REG2)
/Monitor and Cell Balancing/CELL 0: D1.2, Q1.2, R17.1
/Monitor and Cell Balancing/CELL 1: D2.2, Q2.2, R1.1, R2.1, R19.1
/Monitor and Cell Balancing/CELL 2: D3.2, Q3.2, R3.1, R4.1, R21.1
/Monitor and Cell Balancing/CELL 3: D4.2, Q4.2, R5.1, R6.1, R23.1
/Monitor and Cell Balancing/CELL 4: D5.2, Q5.2, R7.1, R8.1, R25.1
/Monitor and Cell Balancing/CELL 5: D6.2, Q6.2, R9.1, R10.1, R27.1
/Monitor and Cell Balancing/CELL 6: D7.2, Q7.2, R11.1, R12.1, R29.1
/Monitor and Cell Balancing/CELL 7: D8.2, Q8.2, R13.1, R14.1, R31.1
/Monitor and Cell Balancing/CELL 8: D12.2, Q9.2, R15.1, R16.1, R33.1
/Monitor and Cell Balancing/CELL 9: D13.2, P3.10, Q10.2, R36.1, R37.1, R52.1
/Monitor and Cell Balancing/CELL 10: D14.2, P3.11, Q11.2, R38.1, R39.1, R47.2, R54.1
/Monitor and Cell Balancing/CELL 11: D15.2, P3.12, Q12.2, R40.1, R41.1, R56.1
/Monitor and Cell Balancing/CELL 12: D16.2, P3.13, Q13.2, R34.1, R42.1, R43.1, R58.1
/Monitor and Cell Balancing/CELL 13: D17.2, P3.14, Q14.2, R34.2, R44.1, R45.1, R60.1
/Monitor and Cell Balancing/CELL 14: D18.2, P3.15, Q15.2, R71.2, R72.1, R73.1, R79.1
/Monitor and Cell Balancing/CELL 15: D19.2, P3.16, Q16.2, R71.1, R74.1, R75.1, R81.1
/Monitor and Cell Balancing/CELL 16: D11.2 (A), D20.2 (A), D30.2 (A), P3.17, Q17.2 (S), R47.1, R76.1, R77.1, R83.1, R92.2
/Monitor and Cell Balancing/DSG: D35.1, R130.1, U1.43 (DSG)
/Monitor and Cell Balancing/FUSE_AFE: R114.1, U1.38 (FUSE)
/Monitor and Cell Balancing/LD: D41.1, D44.2, R138.1, U1.41 (LD)
/Monitor and Cell Balancing/PACK: D43.1, R139.1, U1.42 (PACK)
/Monitor and Cell Balancing/SRN: C32.1, C33.1, R95.2, U1.20 (SRN)
/Monitor and Cell Balancing/SRP: C32.2, C33.2, R96.2, U1.18 (SRP)
/Monitor and Cell Balancing/TS1: C28.2, RT1.1, U1.21 (TS1)
/Monitor and Cell Balancing/TS2: C30.1, RT2.2, U1.23 (TS3)
/Monitor and Cell Balancing/TS3: C31.1, RT3.2, U1.28 (HDQ)
/Monitor and Cell Balancing/TS4: C34.1, RT4.2, U1.29 (CFETOFF)
/Monitor and Cell Balancing/VC0: C1.2, D9.1, D10.1, R17.2, R18.2, U1.16 (VC0)
/Monitor and Cell Balancing/VC1: C2.1, C9.2, R19.2, R20.2, U1.15 (VC1)
/Monitor and Cell Balancing/VC2: C2.2, C3.1, R21.2, R22.2, U1.14 (VC2)
/Monitor and Cell Balancing/VC3: C3.2, C4.1, R23.2, R24.2, U1.13 (VC3)
/Monitor and Cell Balancing/VC4: C4.2, C5.1, R25.2, R26.2, U1.12 (VC4)
/Monitor and Cell Balancing/VC5: C5.2, C6.1, R27.2, R28.2, R67.1, R69.2
/Monitor and Cell Balancing/VC6: C6.2, C7.1, R29.2, R30.2, R64.1, R65.2
/Monitor and Cell Balancing/VC7: C7.2, C8.1, R31.2, R32.2, R66.1, R70.2
/Monitor and Cell Balancing/VC8: C8.2, C10.1, R33.2, R50.1, R51.2, R62.2
/Monitor and Cell Balancing/VC9: C10.2, C11.1, R49.1, R52.2, R53.2, R68.2
/Monitor and Cell Balancing/VC10: C11.2, C12.1, R48.1, R54.2, R55.2, R63.2
/Monitor and Cell Balancing/VC11: C12.2, C13.1, R56.2, R57.2, U1.5 (VC11)
/Monitor and Cell Balancing/VC12: C13.2, C14.1, R46.1, R50.2, R58.2, R59.2, U1.4 (VC12)
/Monitor and Cell Balancing/VC13: C14.2, C20.1, R46.2, R60.2, R78.2, U1.3 (VC13)
/Monitor and Cell Balancing/VC14: C20.2, R35.1, R49.2, R79.2, U1.2 (VC14)
/Monitor and Cell Balancing/VC15: C21.2, C22.1, R35.2, R81.2, R82.2, U1.1 (VC15)
/Monitor and Cell Balancing/VC16: C22.2, R48.2, R83.2, U1.48 (VC16)
/Monitor and Cell Balancing/WAKE: C17.2, R84.1, U1.22 (TS2)
/PACK+: C58.2, C60.2, D39.2, D40.2, D47.1, Q25.3, Q26.3, Q27.3, Q29.2 (S), R127.2, R128.2, R131.2, R135.2, R137.2, R140.2, R141.2, R142.2
/PACK-: C59.1, D45.2, D46.2, D47.2, R95.1, R112.2, R113.2, R136.1
GND: C1.1, C9.1, C15.2, C16.2, C17.1, C19.1, C23.1, C24.1, C25.2, C26.2, C27.1, C28.1, C29.1, C30.2, C31.2, C34.2, C35.2, C36.2, C37.1, C38.2, C39.1, C40.2, C41.2, C42.2, C43.2, C44.1, C45.1, C46.1, C47.2, C48.2, C52.2, C53.2, C54.2, D9.2, D10.2, D21.2, D22.2, D26.2, D33.2, D35.2, D36.2, D41.2, D43.2, P1.1, Q18.2, Q20.2, R85.2, R89.1, R90.1, R99.1, R100.1, R101.1, R111.1, R116.1, R120.1, RT1.2, RT2.1, RT3.1, RT4.1, RT5.2 (+), S1.2 (A), S2.2 (B), U1.17 (VSS), U2.1 (GND), U2.5 (NC_2), U3.11 (DVSS), U4.2 (GND), U5.1 (GND), U5.9 (PAD)
unnamed: C15.1, C16.1, C18.1, R61.2, U1.47 (BAT)
unnamed: C18.2, U1.46 (CP1)
unnamed: C19.2, U1.24 (REG18)
unnamed: C21.1, R80.2
unnamed: C26.1, U1.35 (REG1)
unnamed: C27.2, Q19.2 (E), U1.36 (REGIN)
unnamed: C29.2, Q19.3 (C), R94.1
unnamed: C40.1, R108.2, RT5.1 (-), U3.36 (P5.1/TB2.2/MFM.TX/A9)
unnamed: C43.1, R109.2, R110.1
unnamed: C44.2, D30.1 (K), L1.1
unnamed: C45.2, L1.2, R115.1
unnamed: C46.2, C47.1, R115.2, U5.2 (VIN)
unnamed: C48.1, R118.1
unnamed: C49.1, L2.1, R118.2, R119.1, U5.8 (SW)
unnamed: C49.2, R117.2
unnamed: C50.1, R120.2, R121.2, U5.5 (FB)
unnamed: C50.2, C51.1, R119.2
unnamed: C55.2, C56.1
unnamed: C57.1, D32.2, F1.2, Q21.3, Q22.3, Q23.3, R122.1, R124.2
unnamed: C57.2, C58.1
unnamed: C59.2, C60.1
unnamed: D1.1, Q1.1, R18.1
unnamed: D2.1, Q2.1, R20.1
unnamed: D3.1, Q3.1, R22.1
unnamed: D4.1, Q4.1, R24.1
unnamed: D5.1, Q5.1, R26.1
unnamed: D6.1, Q6.1, R28.1
unnamed: D7.1, Q7.1, R30.1
unnamed: D8.1, Q8.1, R32.1
unnamed: D11.1 (K), R61.1
unnamed: D12.1, Q9.1, R51.1
unnamed: D13.1, Q10.1, R53.1
unnamed: D14.1, Q11.1, R55.1
unnamed: D15.1, Q12.1, R57.1
unnamed: D16.1, Q13.1, R59.1
unnamed: D17.1, Q14.1, R78.1
unnamed: D18.1, Q15.1, R80.1
unnamed: D19.1, Q16.1, R82.1
unnamed: D20.1 (K), R94.2
unnamed: D21.1, P1.2, R97.1
unnamed: D22.1, P1.3, R98.1
unnamed: D23.2, R99.2
unnamed: D24.2, R100.2
unnamed: D25.2, R101.2
unnamed: D32.1, L3.1, L4.1, L5.1, R123.2, R124.1
unnamed: D34.1, Q21.2, Q22.2, Q23.2, Q24.4 (S), Q25.2, Q26.2, Q27.2, R126.1
unnamed: D34.2, Q24.3 (G), R125.2, R126.2
unnamed: D36.1, R130.2, R132.1
unnamed: D37.1 (K), D38.2, Q28.1, R129.2
unnamed: D37.2 (A), R129.1, R133.2
unnamed: D38.1, D39.1, L6.2, L7.2, L8.2, Q28.2, R131.1, R134.1
unnamed: D40.1, D42.1, Q29.1 (G), R137.1
unnamed: D42.2, R136.2
unnamed: D44.1, D46.1, R138.2, R141.1, R142.1
unnamed: D45.1, R139.2, R140.1
unnamed: L3.2, Q21.1
unnamed: L4.2, Q22.1
unnamed: L5.2, Q23.1
unnamed: L6.1, Q25.1
unnamed: L7.1, Q26.1
unnamed: L8.1, Q27.1
unnamed: Q1.3, R1.2, R2.2
unnamed: Q2.3, R3.2, R4.2
unnamed: Q3.3, R5.2, R6.2
unnamed: Q4.3, R7.2, R8.2
unnamed: Q5.3, R9.2, R10.2
unnamed: Q6.3, R11.2, R12.2
unnamed: Q7.3, R13.2, R14.2
unnamed: Q8.3, R15.2, R16.2
unnamed: Q9.3, R36.2, R37.2
unnamed: Q10.3, R38.2, R39.2
unnamed: Q11.3, R40.2, R41.2
unnamed: Q12.3, R42.2, R43.2
unnamed: Q13.3, R44.2, R45.2
unnamed: Q14.3, R72.2, R73.2
unnamed: Q15.3, R74.2, R75.2
unnamed: Q16.3, R76.2, R77.2
unnamed: Q17.1 (G), R91.2, R92.1
unnamed: Q17.3 (D), R86.2
unnamed: Q18.3, R91.1
unnamed: Q19.1 (B), R93.2
unnamed: Q20.3, R122.2
unnamed: Q24.1 (D_1), Q24.2 (D_2), Q24.5 (D_3), Q24.6 (D_4), R127.1, R128.1
unnamed: Q28.3, R135.1
unnamed: Q29.3 (D), R134.2
unnamed: R62.1, R64.2, U1.8 (VC8)
unnamed: R63.1, R66.2, U1.6 (VC10)
unnamed: R65.1, R67.2, U1.10 (VC6)
unnamed: R68.1, U1.7 (VC9)
unnamed: R69.1, U1.11 (VC5)
unnamed: R70.1, U1.9 (VC7)
unnamed: R84.2, S1.1 (K)
unnamed: R87.1, U1.26 (SCL)
unnamed: R88.1, U1.27 (SDA)
unnamed: R93.1, U1.37 (BREG)
unnamed: R105.1, U4.8 (STB)
unnamed: R106.2, U4.4 (RXD)
unnamed: R107.2, U4.1 (TXD)
unnamed: R116.2, U5.4 (RON)
unnamed: R117.1, U5.7 (BST)
unnamed: R132.2, R133.1

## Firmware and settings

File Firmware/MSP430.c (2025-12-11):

#include <msp430.h>
#include <stdio.h>
#include <string.h>


#define USE_UART 1
#define USE_I2C_SLAVE 1
#define USE_CAN 1

// Configuration
#define UART_BAUD 115200
#define I2C_SLAVE_ADDR 0x55
#define CAN_BITRATE 500000

typedef struct {
    uint16_t cellVoltages[16];
    uint32_t packVoltage;
    int32_t current;
    int16_t temperatures[4];
    uint8_t soc;
    uint8_t numCells;
    uint8_t protectionFlags;
    uint8_t fetStatus;
    uint16_t balancingStatus;
    uint32_t timestamp;
} SharedBMSData_t;

SharedBMSData_t sharedData = {0};

// I2C Slave register map
uint8_t i2cRegisters[128];
volatile uint8_t i2cRegisterAddress = 0;

void MSP430_I2C_Master_Init(void) {
    // Configure I2C pins (P1.6=SDA, P1.7=SCL for MSP430G2553)
    P1SEL |= BIT6 + BIT7;
    P1SEL2 |= BIT6 + BIT7;
    
    UCB0CTL1 |= UCSWRST;          
    UCB0CTL0 = UCMST + UCMODE_3 + UCSYNC; 
    UCB0CTL1 = UCSSEL_2 + UCSWRST;  
    UCB0BR0 = 12;                     
    UCB0BR1 = 0;
    UCB0CTL1 &= ~UCSWRST;             // Clear SW reset, resume operation
}

bool I2C_Write(uint8_t addr, uint8_t *data, uint8_t length) {
    UCB0I2CSA = addr;                 // Set slave address
    UCB0CTL1 |= UCTR + UCTXSTT;       // I2C TX, start condition
    
    for (uint8_t i = 0; i < length; i++) {
        while (!(IFG2 & UCB0TXIFG));  // Wait for TX buffer ready
        UCB0TXBUF = data[i];           // Transmit data
    }
    
    while (UCB0CTL1 & UCTXSTP);      
    UCB0CTL1 |= UCTXSTP;             
    
    return true;
}

bool I2C_Read(uint8_t addr, uint8_t reg, uint8_t *data, uint8_t length) {
    
    UCB0I2CSA = addr;
    UCB0CTL1 |= UCTR + UCTXSTT;       // I2C TX, start
    while (!(IFG2 & UCB0TXIFG));
    UCB0TXBUF = reg;
    while (!(IFG2 & UCB0TXIFG));
    
    // Read data
    UCB0CTL1 &= ~UCTR;                // I2C RX
    UCB0CTL1 |= UCTXSTT;              // Repeated start
    
    for (uint8_t i = 0; i < length; i++) {
        if (i == length - 1) {
            UCB0CTL1 |= UCTXSTP;      // Send stop before last byte
        }
        while (!(IFG2 & UCB0RXIFG));
        data[i] = UCB0RXBUF;
    }
    
    return true;
}

void MSP430_UART_Init(void) {
    // Configure UART pins (P1.1=RX, P1.2=TX)
    P1SEL |= BIT1 + BIT2;
    P1SEL2 |= BIT1 + BIT2;
    
    UCA0CTL1 |= UCSSEL_2;             // SMCLK
    UCA0BR0 = 104;                    // 1MHz/115200 = 8.68
    UCA0BR1 = 0;
    UCA0MCTL = UCBRS0;                // Modulation
    UCA0CTL1 &= ~UCSWRST;             // Initialize USCI state machine
    IE2 |= UCA0RXIE;                  // Enable USCI_A0 RX interrupt
}

void UART_SendChar(char c) {
    while (!(IFG2 & UCA0TXIFG));      // Wait for TX buffer ready
    UCA0TXBUF = c;
}

void UART_SendString(const char *str) {
    while (*str) {
        UART_SendChar(*str++);
    }
}

void UART_Printf(const char *format, ...) {
    char buffer[128];
    va_list args;
    va_start(args, format);
    vsnprintf(buffer, sizeof(buffer), format, args);
    va_end(args);
    UART_SendString(buffer);
}

void UART_SendBMSData(void) {
    UART_Printf("SOC: %d%%\r\n", sharedData.soc);
    UART_Printf("Pack Voltage: %ld.%03ldV\r\n", 
                sharedData.packVoltage / 1000,
                sharedData.packVoltage % 1000);
    UART_Printf("Current: %s%ld.%03ldA\r\n",
                sharedData.current >= 0 ? "+" : "",
                sharedData.current / 1000,
                abs(sharedData.current) % 1000);
    
    UART_SendString("\r\nCell Voltages:\r\n");
    for (uint8_t i = 0; i < sharedData.numCells; i++) {
        UART_Printf("  Cell %2d: %d.%03dV", i+1,
                    sharedData.cellVoltages[i] / 1000,
                    sharedData.cellVoltages[i] % 1000);
        if (sharedData.balancingStatus & (1 << i)) {
            UART_SendString(" [BAL]");
        }
        UART_SendString("\r\n");
    }
    
    UART_SendString("\r\nTemperatures:\r\n");
    for (uint8_t i = 0; i < 4; i++) {
        UART_Printf("  Sensor %d: %d.%d°C\r\n", i+1,
                    sharedData.temperatures[i] / 10,
                    abs(sharedData.temperatures[i]) % 10);
    }
  
}

void UpdateSharedData(BQ76952_Data_t *bqData) {
    
    memcpy(sharedData.cellVoltages, bqData->cellVoltages, sizeof(sharedData.cellVoltages));
    sharedData.packVoltage = bqData->stackVoltage;
    sharedData.current = bqData->current;
    memcpy(sharedData.temperatures, bqData->temperatures, sizeof(sharedData.temperatures));
    sharedData.soc = bqData->soc;
    sharedData.numCells = bqData->numCells;
    
    
    sharedData.protectionFlags = 0;
    sharedData.protectionFlags |= (bqData->protectionStatus.overvoltage << 0);
    sharedData.protectionFlags |= (bqData->protectionStatus.undervoltage << 1);
    sharedData.protectionFlags |= (bqData->protectionStatus.overcurrentCharge << 2);
    sharedData.protectionFlags |= (bqData->protectionStatus.overcurrentDischarge << 3);
    sharedData.protectionFlags |= (bqData->protectionStatus.overtemperature << 4);
    sharedData.protectionFlags |= (bqData->protectionStatus.undertemperature << 5);
    sharedData.protectionFlags |= (bqData->protectionStatus.shortCircuit << 6);
    

    sharedData.fetStatus = 0;
    sharedData.fetStatus |= (bqData->fetStatus.chargeFET << 0);
    sharedData.fetStatus |= (bqData->fetStatus.dischargeFET << 1);
    
    // Balancing
    sharedData.balancingStatus = bqData->balancingCells;
}


void main(void) {
    WDTCTL = WDTPW | WDTHOLD;        
    
    // Configure clock
    BCSCTL1 = CALBC1_1MHZ;            
    DCOCTL = CALDCO_1MHZ;
    
 
    MSP430_I2C_Master_Init();
    MSP430_UART_Init();
    
  
    BQ76952_Init();
  
    __enable_interrupt();    
    
  
    while (1) {
       
        BQ76952_UpdateAll(&bqData);
        
      
        UpdateSharedData(&bqData);
        
    
        static uint16_t uartCounter = 0;
        if (++uartCounter >= 10) {
            uartCounter = 0;
            UART_SendBMSData();
        }
          
        __delay_cycles(100000);
    }
}

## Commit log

2025-12-11 Add BQ76952 initialization and read functions
    Implement BQ76952 battery management functions
2025-12-11 Add BQ76952 header file with definitions and prototypes
2025-12-11 Add MSP430 BMS communication and data handling
2025-12-11 Add README for Battery Management System project
    Added comprehensive documentation for the Battery Management System project, including project overview, specifications, features, hardware components, design processes, testing, and safety notes.
